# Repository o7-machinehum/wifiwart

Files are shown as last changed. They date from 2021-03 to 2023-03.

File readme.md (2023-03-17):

# Wifiwart
## Custom Non Form Factor Board
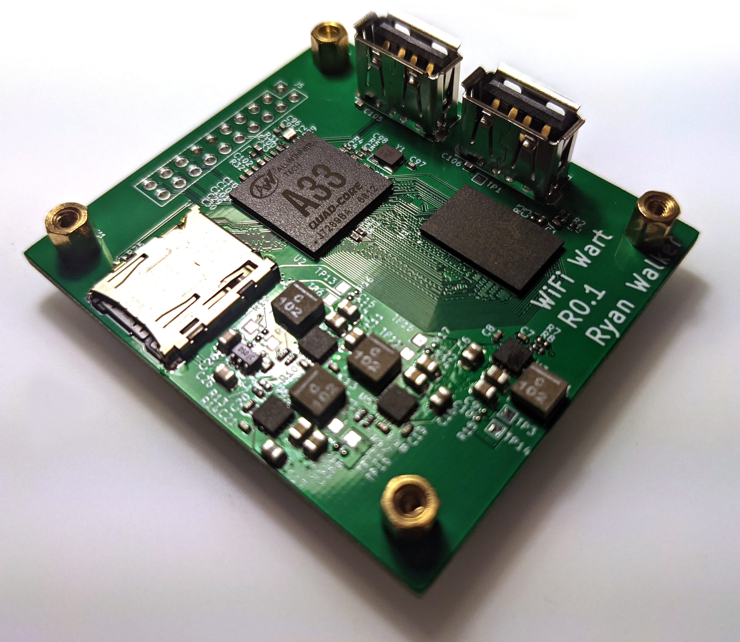
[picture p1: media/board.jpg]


## Final boards
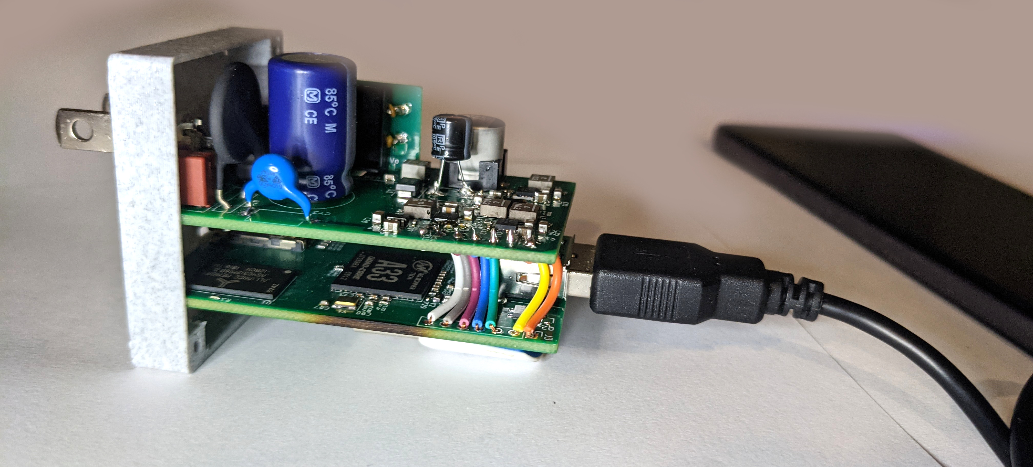
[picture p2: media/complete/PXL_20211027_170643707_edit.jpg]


The WiFiWart is an open source WiFi penetration device masquerading as a 
wall charger. It features a 1.2Ghz Cortex A7 MPU with two WiFi
chips. The electrical, mechanical and software elemenet are all completely
open source. Check out the blog series!

- [Final Blog Post](https://interruptlabs.ca/2021/10/25/I-put-a-WiFi-router-into-a-phone-charger-Final-Post/)
- [Blog Post #3](https://interruptlabs.ca/2021/09/22/I'm-not-putting-a-WiFi-router-into-a-phone-charger-Part-3/)
- [Blog Post #2](https://interruptlabs.ca/2021/07/19/I'm-putting-a-WiFi-router-into-a-wall-charger-Part-2/)
- [Blog Post #1](https://interruptlabs.ca/2021/06/15/I'm-putting-a-WiFi-router-into-a-wall-charger-Part-1/)
- [Blog Post #0](https://interruptlabs.ca/2021/04/28/I'm-putting-a-WiFi-router-into-a-wall-charger-Part-0/)
- [Join us on Discord!](https://discord.gg/EtZT7mjNuM)

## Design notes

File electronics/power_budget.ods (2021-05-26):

DC
Vin (Vdc) | Vout (Vdc) | Iin (A) | Iout (A) | Pin (W) | Pout (W) | Supply Efficiency | Waste Heat (W)
5 | 3.3 | 0.776470588235294 | 1 | 3.88235294117647 | 3.3 | 0.85 | 0.58235294117647
5 | 3 | 0.705882352941176 | 1 | 3.52941176470588 | 3 | 0.85 | 0.529411764705883
3.3 | 2.5 | 0.3 | 0.3 | 0.99 | 0.75 | 0.757575757575758 | 0.24
5 | 1.35 | 0.635294117647059 | 2 | 3.17647058823529 | 2.7 | 0.85 | 0.476470588235294
5 | 1.1 | 1.03529411764706 | 4 | 5.17647058823529 | 4.4 | 0.85 | 0.776470588235294
 | Total: | 3.45294117647059 |  |  |  |  | 2.60470588235294
Vin (RMS) | Vin (pk) | Vout (pk) | Windings Ratio
120 | 169.705627484771 | 5.5 | 30.8555686335948

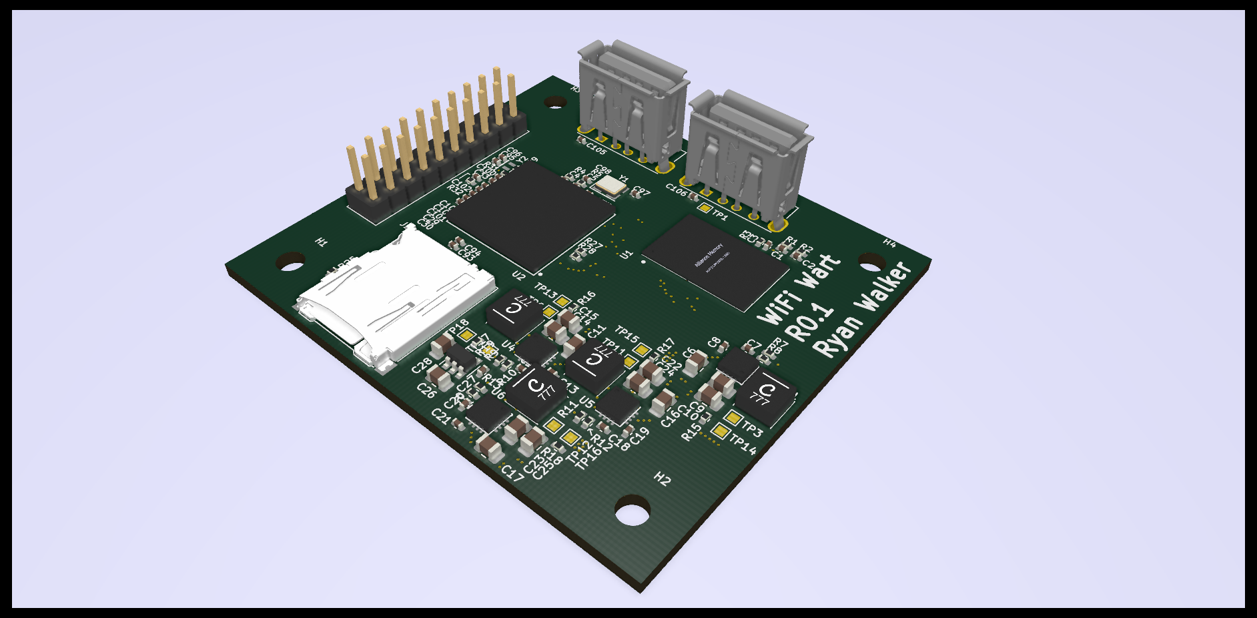
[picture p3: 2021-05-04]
electronics/nff_pcb/Renders/hardware3.png

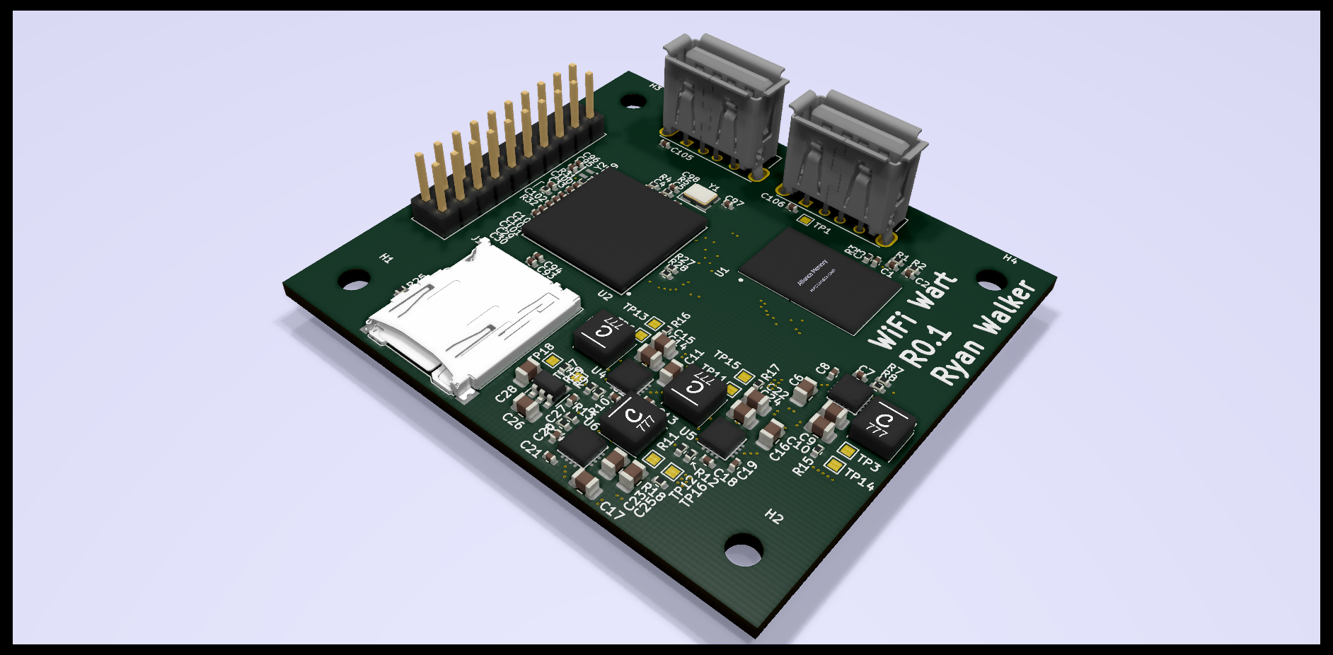
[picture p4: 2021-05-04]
electronics/nff_pcb/Renders/hardware2.png

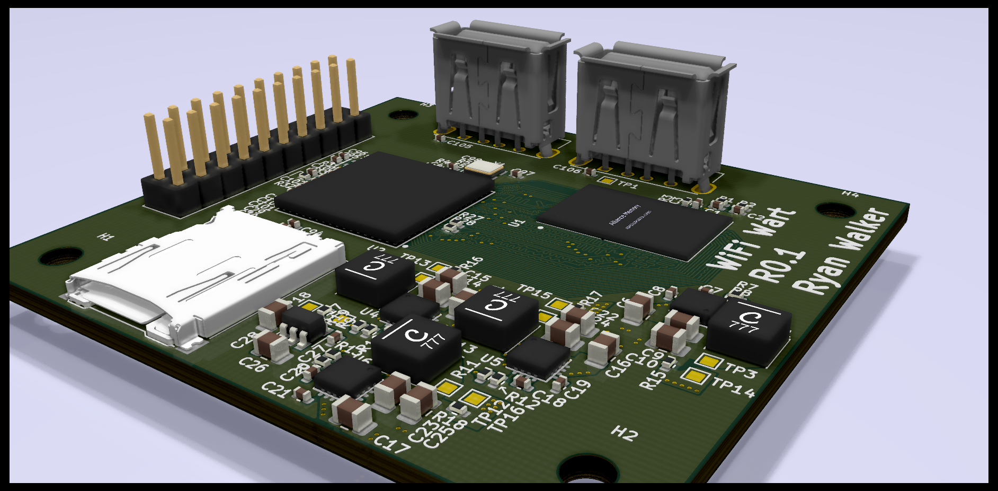
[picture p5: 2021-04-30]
electronics/nff_pcb/Renders/hardware4.png

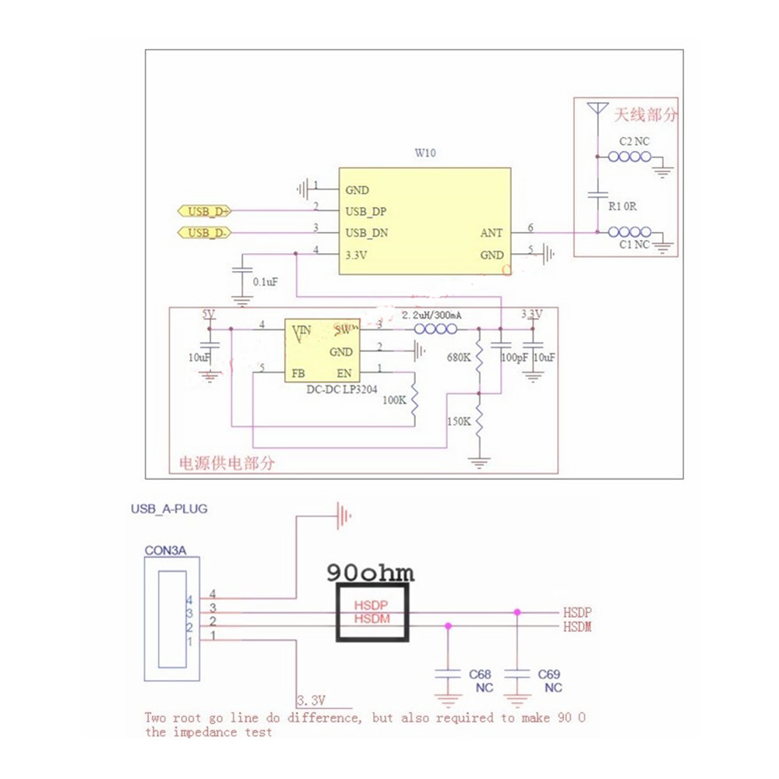
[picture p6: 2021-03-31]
electronics/datasheets/wifi_sch.jpg

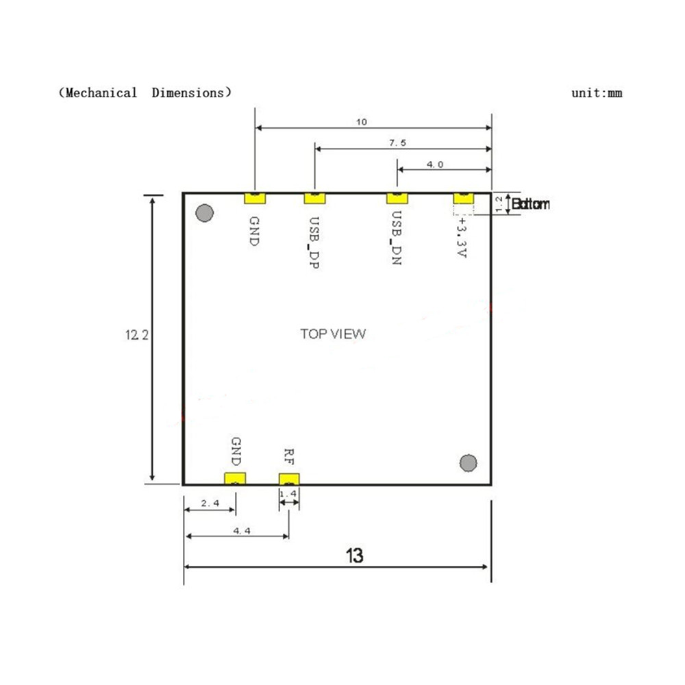
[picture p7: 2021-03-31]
electronics/datasheets/wifi_layout.jpg

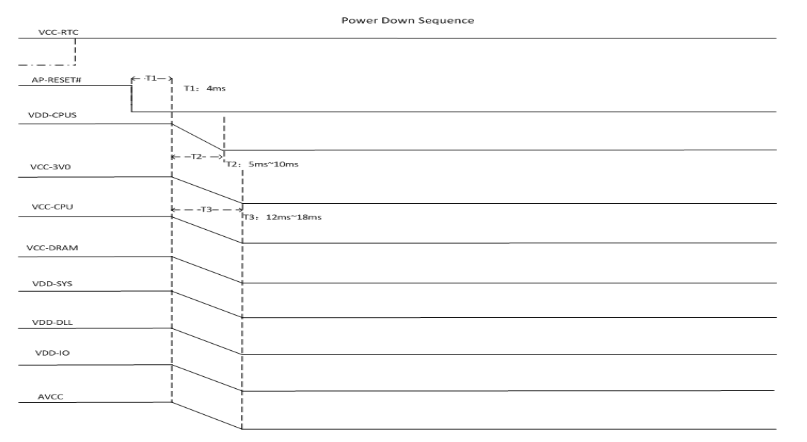
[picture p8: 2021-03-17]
electronics/datasheets/pd.png

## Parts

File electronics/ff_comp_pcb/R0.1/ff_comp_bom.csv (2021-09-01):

Ref | Qnty | Value | Footprint | Part Number
AE1, AE2, | 2 | Antenna_Dipole | Connector_Coaxial:U.FL_Hirose_U.FL-R-SMT-1_Vertical | U.FL-R-SMT-1(10)
C1, C2, C3, C4, C5, C6, C8, C10, C11, C30, C31, C32, C33, C37, C38, C40, C42, C43, C48, C59, C64, C65, C66, C67, C68, C73, C74, C75, C76, C77, C78, C79, C80, C82, C85, C86, C87, C89, C90, C91, C92, C93, C100, C104, | 44 | 100nF | Capacitor_SMD:C_0402_1005Metric | CC0402KRX7R7BB104
C7, C9, C53, C54, C55, C56, C69, C70, C94, | 9 | 22uF | Capacitor_SMD:C_0402_1005Metric | GRM155R60J226ME11D
C29, C99, C102, C103, | 4 | 10uF | Capacitor_SMD:C_0402_1005Metric | CL05A106MQ5NUNC
C95, C96, | 2 | 10pF | Capacitor_SMD:C_0402_1005Metric | CC0402JRNPO9BN100
C97, C98, | 2 | 30pF | Capacitor_SMD:C_0402_1005Metric | CC0402JRNPO9BN300
C101, | 1 | 1uF | Capacitor_SMD:C_0402_1005Metric | CL05A105KO5NNNC
J1, | 1 | Micro_SD_Card_Det_Hirose_DM3AT | Connector_Card:microSD_HC_Hirose_DM3AT-SF-PEJM5 | DM3AT-SF-PEJM5
J2, | 1 | USB_A | Connector_USB:USB_A_Molex_67643_Horizontal | 676430910
J3, | 1 | Conn_01x07_Female | Connector_PinHeader_2.54mm:PinHeader_1x07_P2.54mm_Vertical
J4, | 1 | Conn_01x03_Male | Connector_PinHeader_2.54mm:PinHeader_1x03_P2.54mm_Vertical
Q1, | 1 | Q_PMOS_GSD | Package_TO_SOT_SMD:SOT-23 | SSM3J328R,LF
Q2, | 1 | Q_NPN_BEC | Package_TO_SOT_SMD:SOT-23 | MMBT2369ALT1G
R1, R2, R4, R5, | 4 | 1k | Resistor_SMD:R_0402_1005Metric | 4-1879208-9
R3, R6, | 2 | 240R | Resistor_SMD:R_0402_1005Metric | 0402WGF2400TCE
R7, R20, R21, R23, R24, R25, | 6 | 100k | Resistor_SMD:R_0402_1005Metric | CR0402-JW-104GLF
R22, R30, | 2 | 10k | Resistor_SMD:R_0402_1005Metric | RC0402JR-0710KL
R26, | 1 | 0R | Resistor_SMD:R_0402_1005Metric | RC0402JR-070RL
R27, R28, | 2 | 22R | Resistor_SMD:R_0402_1005Metric | RC0402JR-0722RL
R29, R31, | 2 | 10M | Resistor_SMD:R_0402_1005Metric | 0402WGJ0106TCE
R32, | 1 | 200k | Resistor_SMD:R_0402_1005Metric | RC0402FR-07200KL
TP1, | 1 | TestPoint | TestPoint:TestPoint_Pad_2.0x2.0mm
U1, | 1 | AS4C512M16D3L-12BIN | AS4C512M16D3L:Alliance_Memory-AS4C512M16D3L-12BIN-0-0-IPC_A | AS4C512M16D3L-12BIN
U2, | 1 | A33 | A33_FP:Allwinner_Technology_Co.,_Ltd.-A33-0 | A33
U3, | 1 | FSUSB42MUX | Package_SO:MSOP-10_3x3mm_P0.5mm | FSUSB42MUX
U4, U5, | 2 | RTL8188CUS | realtek:RTL8188CUS | RTL8188CUS
Y1, | 1 | 24Mhz | Crystal:Crystal_SMD_Abracon_ABM8G-4Pin_3.2x2.5mm | ABM8G-24.000MHZ-18-D2Y-T
Y2, | 1 | 32.768khz | Abracon:Abracon-ABS05-0-0-MFG | ABS05-32.768KHZ-9-T

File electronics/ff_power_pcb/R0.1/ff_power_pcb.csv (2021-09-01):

Ref | Qnty | Value | Footprint | Part Number
C1, | 1 | 0.1uF | Capacitor_SMD:C_1206_3216Metric | C3216X7T2V104M160AA
C2, | 1 | 10uF | Capacitor_THT:C_Radial_D12.5mm_H20.0mm_P5.00mm | UVR2W100MHD
C4, | 1 | 470uF | Capacitor_SMD:CP_Elec_10x12.5 | GYA1C471MCW1GS
C5, | 1 | 100uF | Capacitor_SMD:CP_Elec_6.3x5.8 | 16ML100MEFC6.3X7
C6, C9, C10, C11, C14, C15, C16, C17, C22, C23, C24, C25, | 12 | 22uF | Capacitor_SMD:C_0805_2012Metric | CL21A226MQQNNNE
C7, C12, C18, C20, | 4 | 10nF | Capacitor_SMD:C_0402_1005Metric | CL05B103KB5NNNC
C8, C13, | 2 | 450pF | Capacitor_SMD:C_0402_1005Metric | CL05B471KB5NNNC
C19, C21, | 2 | 5nF | Capacitor_SMD:C_0402_1005Metric | CC0402KRX7R9BB562
C26, C28, | 2 | 10uF | Capacitor_SMD:C_0805_2012Metric | GRM21BR70J106KE76L
C27, | 1 | 0.1uF | Capacitor_SMD:C_0402_1005Metric | CC0402KRX7R7BB104
C29, | 1 | 0.1uF | Capacitor_SMD:C_0603_1608Metric | C1608X7R1H104K080AA
CY3, | 1 | 1.0nF | Capacitor_THT:C_Disc_D7.5mm_W5.0mm_P10.00mm | C901U102MUVDBA7317
D1, | 1 | SMBJ7.0A | Diode_SMD:D_SMB | SMBJ7.0A
F1, | 1 | 1A/300V Slow | Fuse:Fuse_Littelfuse_395Series | 36911000000
J1, J2, | 2 | Conn_01x01_Female | mains_blade:IRL_00
J3, | 1 | Conn_01x07_Male | Connector_PinSocket_2.54mm:PinSocket_1x07_P2.54mm_Vertical
L1, L2, L3, L4, | 4 | 1uH | Inductor_SMD:L_Coilcraft_XxL4020 | XAL4020-102ME
L5, | 1 | 1.2mH | Bourns:RLB9012 | RLB9012-122KL
L6, | 1 | 4.7uH | Inductor_SMD:L_Coilcraft_XxL4030 | XAL4030-472ME
NTC1, | 1 | 10R | Capacitor_THT:C_Disc_D9.0mm_W2.5mm_P5.00mm | B57234S0100M051
PS1, | 1 | PBO-5C-5 | CUI:CONV_PBO-5C-12 | PBO-5C-5
R7, | 1 | 470k | Resistor_SMD:R_0402_1005Metric | RTT024703FTH
R8, | 1 | 150k | Resistor_SMD:R_0402_1005Metric | RC0402FR-07150KL
R9, | 1 | 330k | Resistor_SMD:R_0402_1005Metric | RC0402FR-07330KL
R10, | 1 | 120k | Resistor_SMD:R_0402_1005Metric | RTT021203FTH
R11, | 1 | 110k | Resistor_SMD:R_0402_1005Metric | RTT021103FTH
R12, | 1 | 160k | Resistor_SMD:R_0402_1005Metric | 0402WGF1603TCE
R13, | 1 | 82k | Resistor_SMD:R_0402_1005Metric | 0402WGF8202TCE
R14, | 1 | 220k | Resistor_SMD:R_0402_1005Metric | ERJPA2F2203X
R15, R16, R17, R18, R19, | 5 | 0R | Resistor_SMD:R_0402_1005Metric | RC0402JR-070RL
U3, U4, U5, U6, | 4 | TPS62095RGTR | TI:TI_RTE_S-PWQFN-N16 | TPS62095RGTR
U7, | 1 | AP131-25 | Package_TO_SOT_SMD:SOT-23-5 | AP131-25

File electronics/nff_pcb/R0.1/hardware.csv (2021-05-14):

Source: | /home/machinehum/projects/wifiwart/electronics/pcb/hardware.sch
Date: | Thu 13 May 2021 02:48:55 PM PDT
Tool: | Eeschema 5.1.10
Generator: | projects/wifiwart/electronics/pcb/generate_bom.py
Component Count: | 145
Ref | Qnty | Value | Footprint | Part Number
C1, C2, C3, C4, C5, C30, C31, C32, C33, C37, C38, C40, C42, C43, C48, C59, C64, C65, C66, C67, C68, C73, C74, C75, C76, C77, C78, C79, C80, C82, C85, C86, C87, C89, C90, C91, C92, C93, C100, C104, | 40 | 100nF | Capacitor_SMD:C_0402_1005Metric | CC0402KRX7R7BB104
C6, C9, C10, C11, C14, C15, C16, C17, C22, C23, C24, C25, | 12 | 22uF | Capacitor_SMD:C_0805_2012Metric | CL21A226MQQNNNE
C7, C12, C18, C20, | 4 | 10nF | Capacitor_SMD:C_0402_1005Metric | CL05B103KB5NNNC
C8, C13, | 2 | 450pF | Capacitor_SMD:C_0402_1005Metric | CL05B471KB5NNNC
C19, C21, | 2 | 5nF | Capacitor_SMD:C_0402_1005Metric | CC0402KRX7R9BB562
C26, C28, | 2 | 10uF | Capacitor_SMD:C_0805_2012Metric | GRM21BR70J106KE76L
C27, | 1 | 0.1uF | Capacitor_SMD:C_0402_1005Metric | CC0402KRX7R7BB104
C29, C99, C102, C103, C105, C106, | 6 | 10uF | Capacitor_SMD:C_0402_1005Metric | CL05A106MQ5NUNC
C53, C54, C55, C56, C69, C70, C94, | 7 | 22uF | Capacitor_SMD:C_0402_1005Metric | GRM155R60J226ME11D
C95, C96, | 2 | 10pF | Capacitor_SMD:C_0402_1005Metric | CC0402JRNPO9BN100
C97, C98, | 2 | 30pF | Capacitor_SMD:C_0402_1005Metric | CC0402JRNPO9BN300
C101, | 1 | 1uF | Capacitor_SMD:C_0402_1005Metric | CL05A105KO5NNNC
H1, H2, H3, H4, | 4 | MountingHole | MountingHole:MountingHole_3.2mm_M3
J1, | 1 | Micro_SD_Card_Det_Hirose_DM3AT | Connector_Card:microSD_HC_Hirose_DM3AT-SF-PEJM5 | DM3AT-SF-PEJM5
J2, J3, | 2 | USB_A | Connector_USB:USB_A_Molex_105057_Vertical | 1050570001
J5, | 1 | Conn_02x10_Odd_Even | Connector_PinHeader_2.54mm:PinHeader_2x10_P2.54mm_Vertical
L1, L2, L3, L4, | 4 | 1uH | Inductor_SMD:L_Coilcraft_XxL4020 | XAL4020-102ME
R1, R2, R4, R5, | 4 | 1k | Resistor_SMD:R_0402_1005Metric | 4-1879208-9
R3, R6, | 2 | 240R | Resistor_SMD:R_0402_1005Metric | 0402WGF2400TCE
R7, | 1 | 470k | Resistor_SMD:R_0402_1005Metric | RTT024703FTH
R8, | 1 | 150k | Resistor_SMD:R_0402_1005Metric | RC0402FR-07150KL
R9, | 1 | 330k | Resistor_SMD:R_0402_1005Metric | RC0402FR-07330KL
R10, | 1 | 120k | Resistor_SMD:R_0402_1005Metric | RTT021203FTH
R11, | 1 | 110k | Resistor_SMD:R_0402_1005Metric | RTT021103FTH
R12, | 1 | 160k | Resistor_SMD:R_0402_1005Metric | 0402WGF1603TCE
R13, | 1 | 82k | Resistor_SMD:R_0402_1005Metric | 0402WGF8202TCE
R14, | 1 | 220k | Resistor_SMD:R_0402_1005Metric | ERJPA2F2203X
R15, R16, R17, R18, R19, R26, | 6 | 0R | Resistor_SMD:R_0402_1005Metric | RC0402JR-070RL
R20, R21, R23, R24, R25, | 5 | 100k | Resistor_SMD:R_0402_1005Metric | CR0402-JW-104GLF
R22, R30, | 2 | 10k | Resistor_SMD:R_0402_1005Metric | RC0402JR-0710KL
R27, R28, | 2 | 22R | Resistor_SMD:R_0402_1005Metric | RC0402JR-0722RL
R29, R31, | 2 | 10M | Resistor_SMD:R_0402_1005Metric | 0402WGJ0106TCE
R32, | 1 | 200k | Resistor_SMD:R_0402_1005Metric | RC0402FR-07200KL
TP1, TP3, TP6, TP11, TP12, TP13, TP14, TP15, TP16, TP17, TP18, | 11 | TestPoint | TestPoint:TestPoint_Pad_1.0x1.0mm | ~
U1, | 1 | AS4C512M16D3L-12BIN | AS4C512M16D3L:Alliance_Memory-AS4C512M16D3L-12BIN-0-0-IPC_A | AS4C512M16D3L-12BIN
U2, | 1 | A33 | A33_FP:Allwinner_Technology_Co.,_Ltd.-A33-0 | A33
U3, U4, U5, U6, | 4 | TPS62095RGTR | TI:TI_RTE_S-PWQFN-N16 | TPS62095RGTR
U7, | 1 | AP131-25 | Package_TO_SOT_SMD:SOT-23-5 | AP131-25
Y1, | 1 | 24Mhz | Crystal:Crystal_SMD_Abracon_ABM8G-4Pin_3.2x2.5mm | ABM8G-24.000MHZ-18-D2Y-T
Y2, | 1 | 32.768khz | Abracon:Abracon-ABS05-0-0-MFG | ABS05-32.768KHZ-9-T

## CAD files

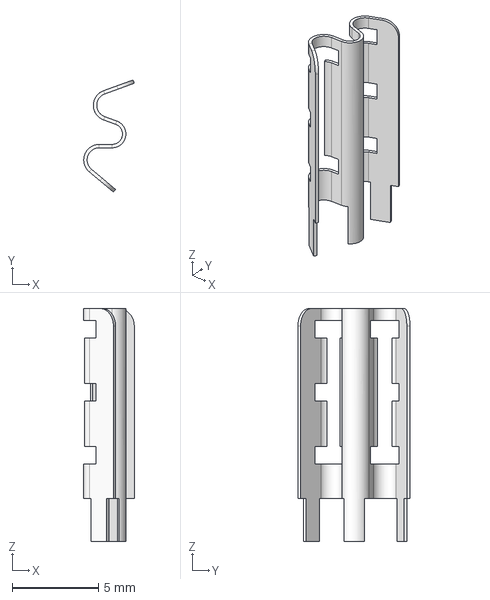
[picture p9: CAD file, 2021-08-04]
electronics/ff_power_pcb/step/mains_blade.step
2.93 x 6.49 x 13.5 mm

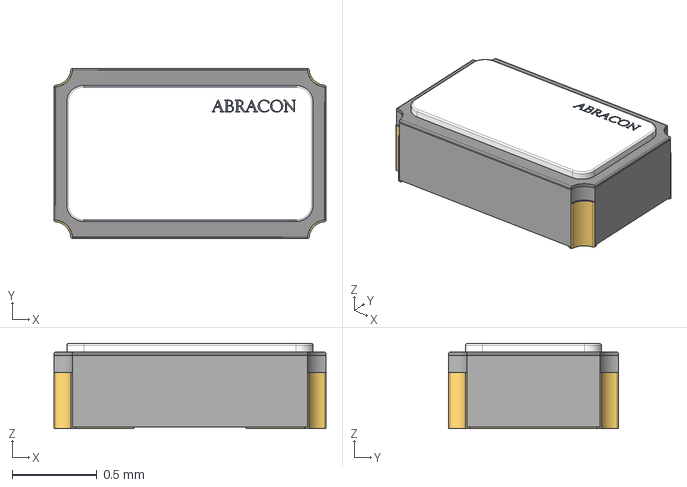
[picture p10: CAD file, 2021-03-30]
electronics/ff_comp_pcb/Abracon/eec.models/Abracon_-_ABS05-32.768KHZ-9-T.step
1.60 x 1.00 x 0.501 mm

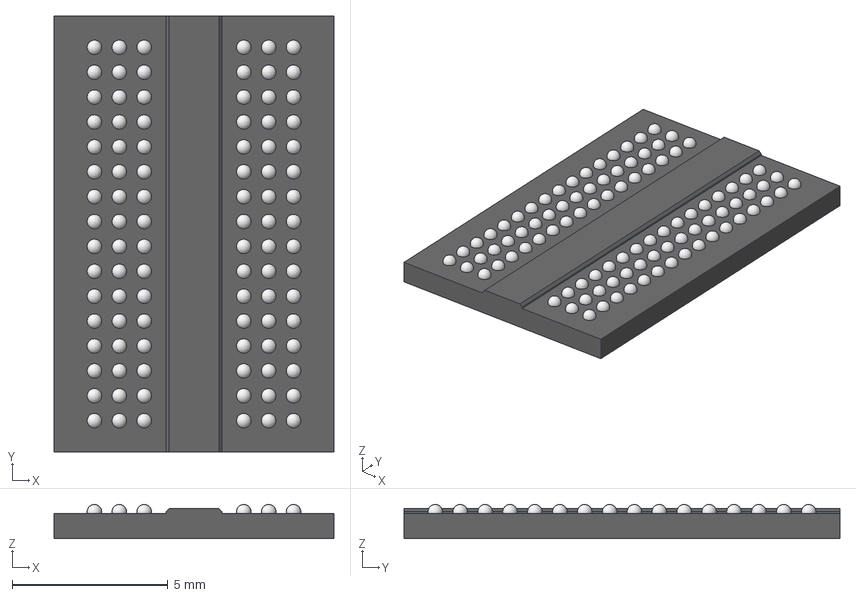
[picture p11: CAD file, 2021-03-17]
electronics/ff_comp_pcb/AS4C512M16D3L/eec.models/Alliance_Memory_-_AS4C512M16D3L-12BIN.step
9.00 x 14.0 x 1.09 mm
Part1cvcvcv
Part2sdsdsdsd x 48
Part2sdsdsdsd_MIR x 48

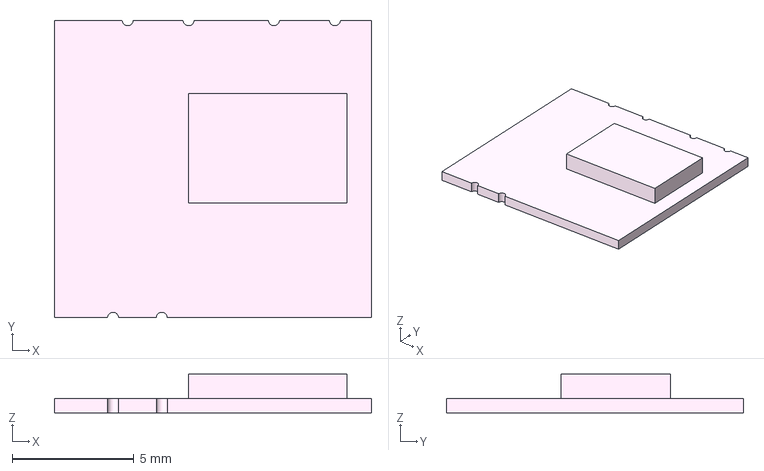
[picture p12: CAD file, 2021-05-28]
electronics/ff_comp_pcb/realtek/RTL8188CUS_module-Body.step
13.0 x 12.2 x 1.58 mm

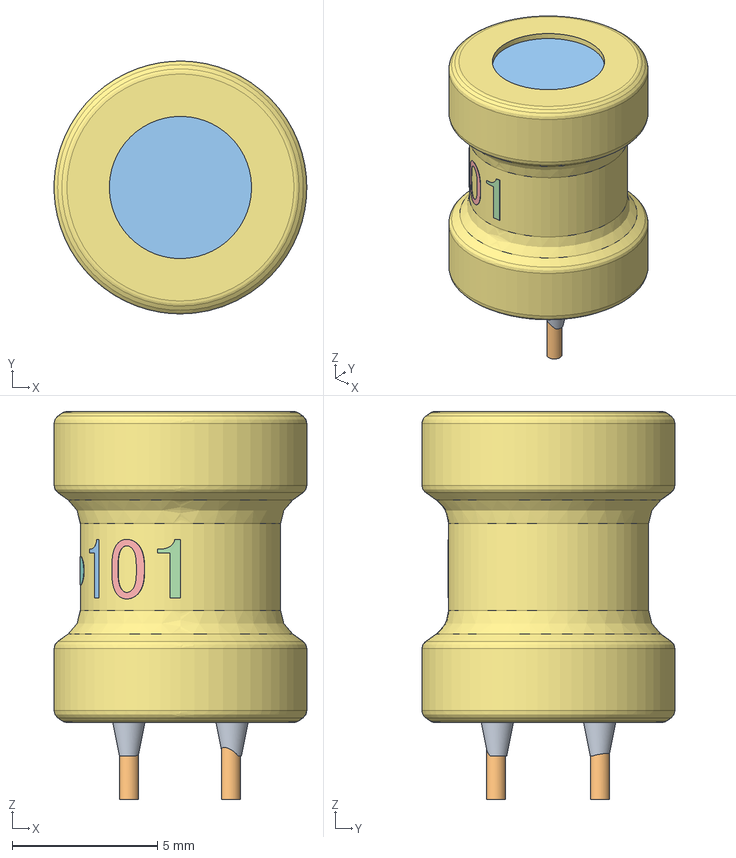
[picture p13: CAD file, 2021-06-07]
electronics/ff_power_pcb/Bourns/rlb9012_short.stp
8.70 x 8.70 x 13.3 mm
Slice.0
Slice.2
Slice.3
Slice.4
Slice.5
Slice.6
Slice.8
Slice.9
Slice.10
Slice.11
Slice.12
Slice.13
Slice.14
Slice.15
Slice.16
Slice.17
Slice.19
Slice.20
Slice.22
Slice.23
Slice.24
Slice.25
Slice.26
Slice.27
Slice.28
Slice.29
Slice.30
Slice.31
Slice.32
Slice.33
Slice.34
Slice.35
Slice.36
Slice.37
Slice.38
Slice.39
Slice.40
Slice.41
Slice.42
Slice.43
Slice.44
Slice.45
Slice.46
Slice.47
Slice.48
Slice.49
Slice.50
Slice.51
Slice.52
Slice.53
Slice.54
Slice.55
Slice.56
Slice.57
Slice.58
Slice.59
Slice.60
Slice.61
Slice.62
Slice.63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

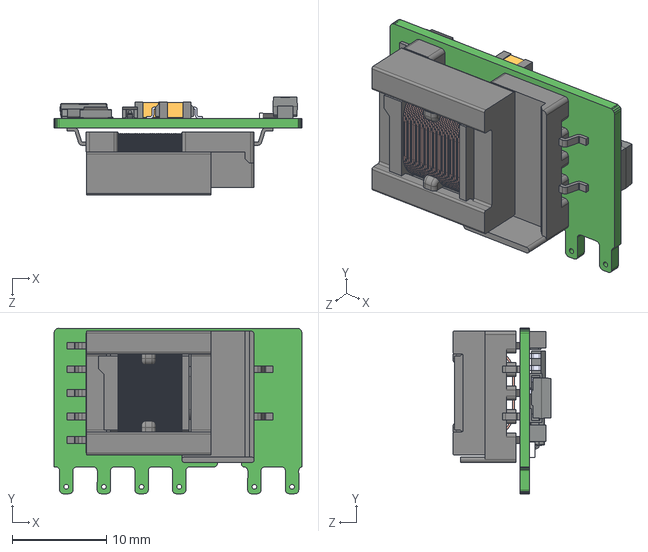
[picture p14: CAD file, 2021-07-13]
electronics/ff_power_pcb/cui/PBO-5C-12.step
26.4 x 17.6 x 10.5 mm

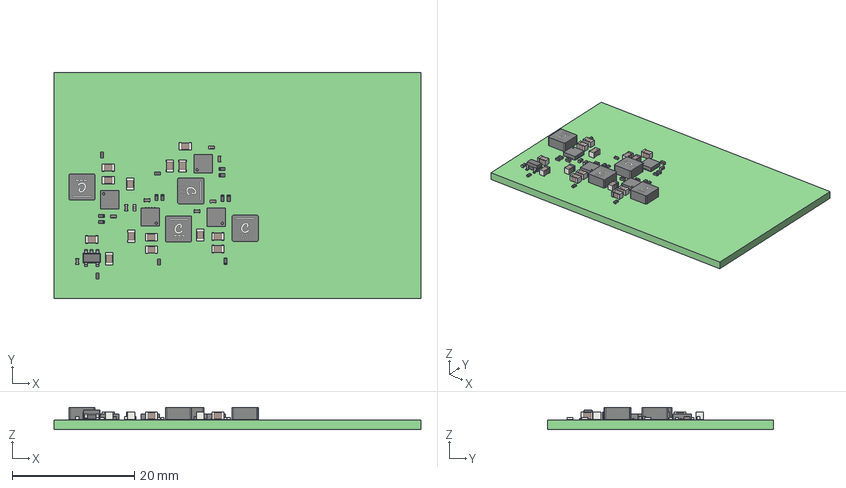
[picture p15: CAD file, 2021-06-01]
electronics/ff_power_pcb/R0.1/hardware.step
60.0 x 37.0 x 3.65 mm

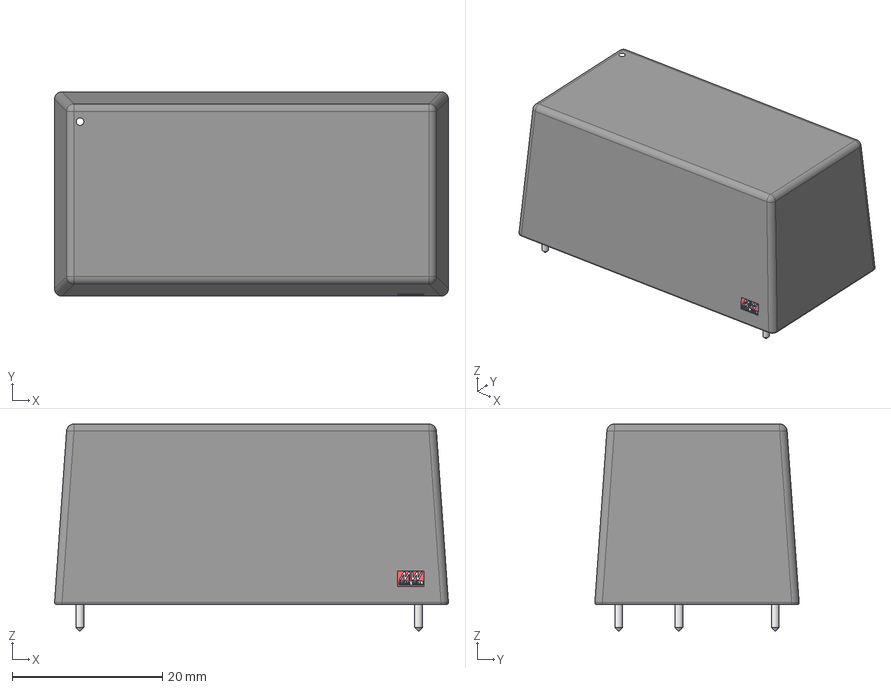
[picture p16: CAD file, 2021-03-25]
electronics/nff_pcb/MPM-15-5/eec.models/MEAN_WELL_-_MPM-15-5.step
52.4 x 27.2 x 27.5 mm
Leads
Mean Well logo
Mean Well txt
Frame
Sillkscreen dot

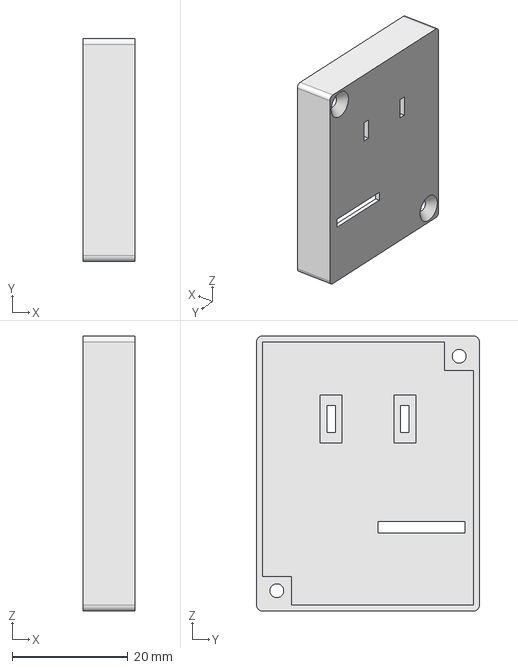
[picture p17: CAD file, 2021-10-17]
mech/lid.FCStd
9.00 x 38.5 x 47.5 mm

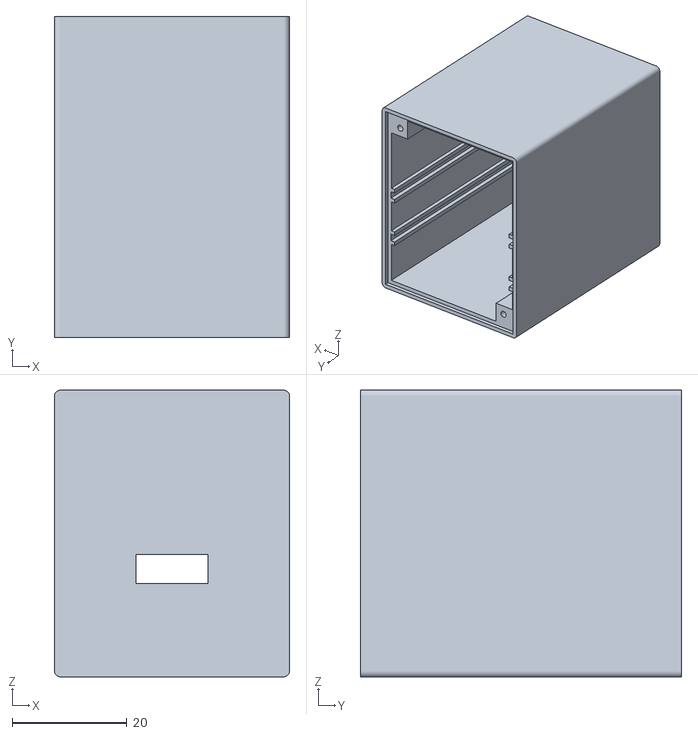
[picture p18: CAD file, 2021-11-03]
mech/out/case-ModelBody-r1.stl
41.0 x 56.0 x 50.0

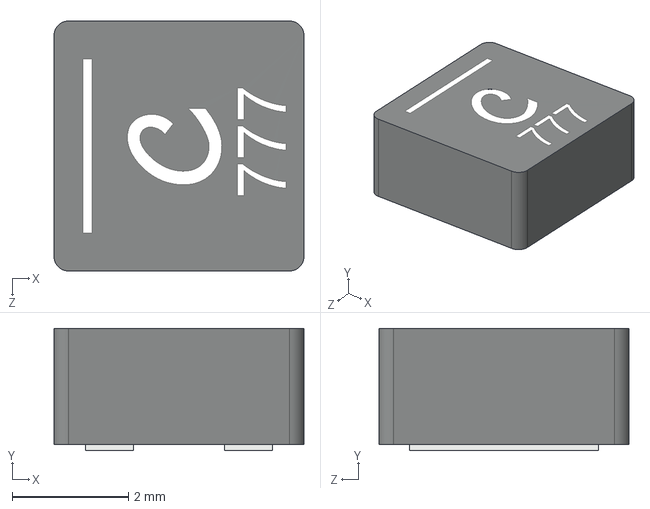
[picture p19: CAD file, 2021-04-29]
electronics/ff_comp_pcb/step/Coilcraft-XAL4020.step
4.30 x 2.10 x 4.30 mm

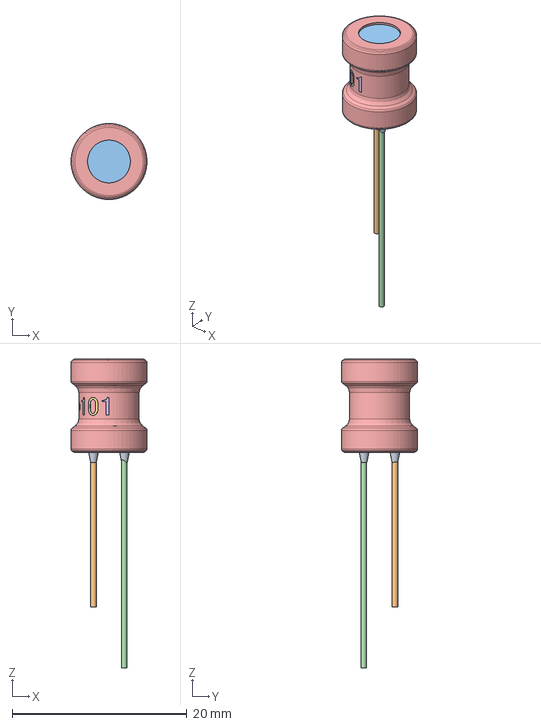
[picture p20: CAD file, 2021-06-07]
electronics/ff_power_pcb/Bourns/rlb9012.stp
8.70 x 8.70 x 35.4 mm

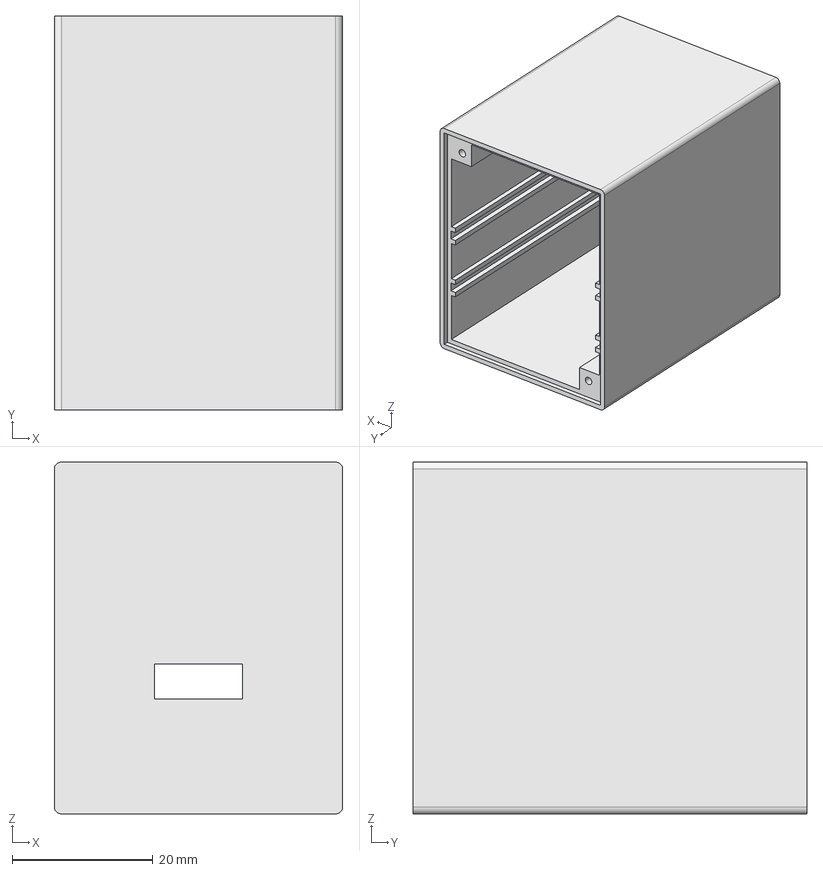
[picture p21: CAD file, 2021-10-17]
mech/case.FCStd
41.0 x 56.0 x 50.0 mm

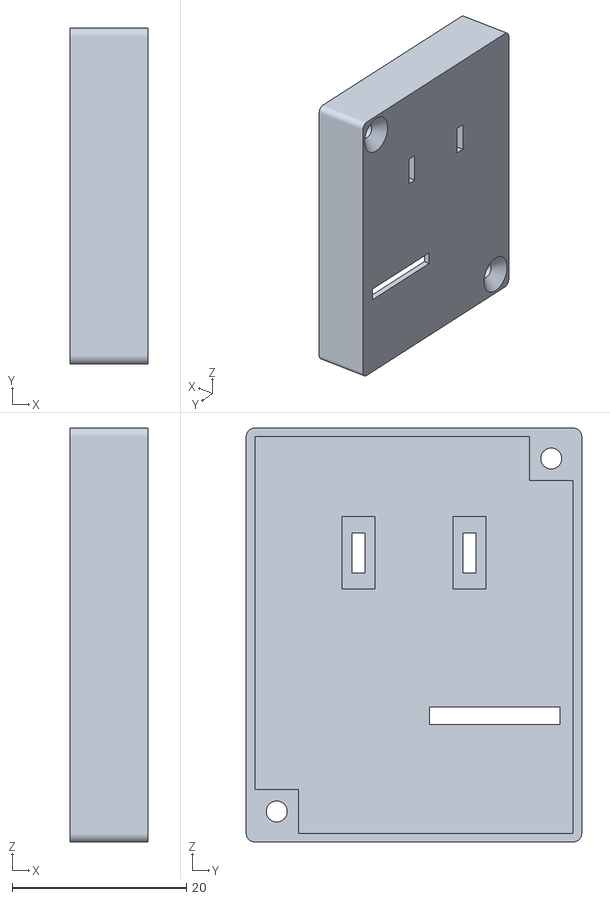
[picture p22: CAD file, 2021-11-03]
mech/out/lid-ModelBody-r1.stl
9.00 x 38.5 x 47.5

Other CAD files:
mech/out/mains_blade-Body.step
mech/mains_blade.FCStd
electronics/ff_comp_pcb/realtek/RTL8188CUS_module.FCStd
electronics/ff_comp_pcb/1050570001/1050570001.stp
electronics/ff_comp_pcb/step/676430910.stp
electronics/ff_comp_pcb/step/DM3AT-SF-PEJM5.stp
electronics/ff_comp_pcb/step/QFN-3x3.step
electronics/ff_power_pcb/Bourns/srr1208.stp
electronics/ff_power_pcb/step/36911000000.step
electronics/ff_power_pcb/step/Coilcraft-XAL4030.step
mech/36911000000.FCStd
mech/comp_pcb.FCStd
mech/out/prong-ModelParts.step
mech/patch_antenna.FCStd
mech/power_pcb.FCStd
mech/prong.FCStd

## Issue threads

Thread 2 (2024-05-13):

What's memory name

hmz06967, 2024-05-13:
Hello, I did a similar project, but I could not find the RAM model suitable for the RAM package you are using. What is the exact name of the chip you are using or can you recommend RAM models suitable for the package?

o7-machinehum, 2024-05-14:
AS4C512M16D3L-12BIN

Good luck :)

hmz06967, 2024-05-14:
But this memory is 8gb, you have installed 1gb of memory

o7-machinehum, 2024-05-14:
8GBIT = 1GBYTE :)

hmz06967, 2024-05-14:
fI'm sorry, I didn't notice it, so can you tell me whether this ram is suitable for this project? https://community.nxp.com/pwmxy87654/attachments/pwmxy87654/imx-processors/44426/2/99H02-11185D.pdf

o7-machinehum, 2024-05-14:
Looks fine to me, but of course I'm not inspecting every pin on the pdf.

Just look though both datasheets and see if the pins match up

hmz06967, 2024-05-14:
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
it just looks empty
Is it a problem ?

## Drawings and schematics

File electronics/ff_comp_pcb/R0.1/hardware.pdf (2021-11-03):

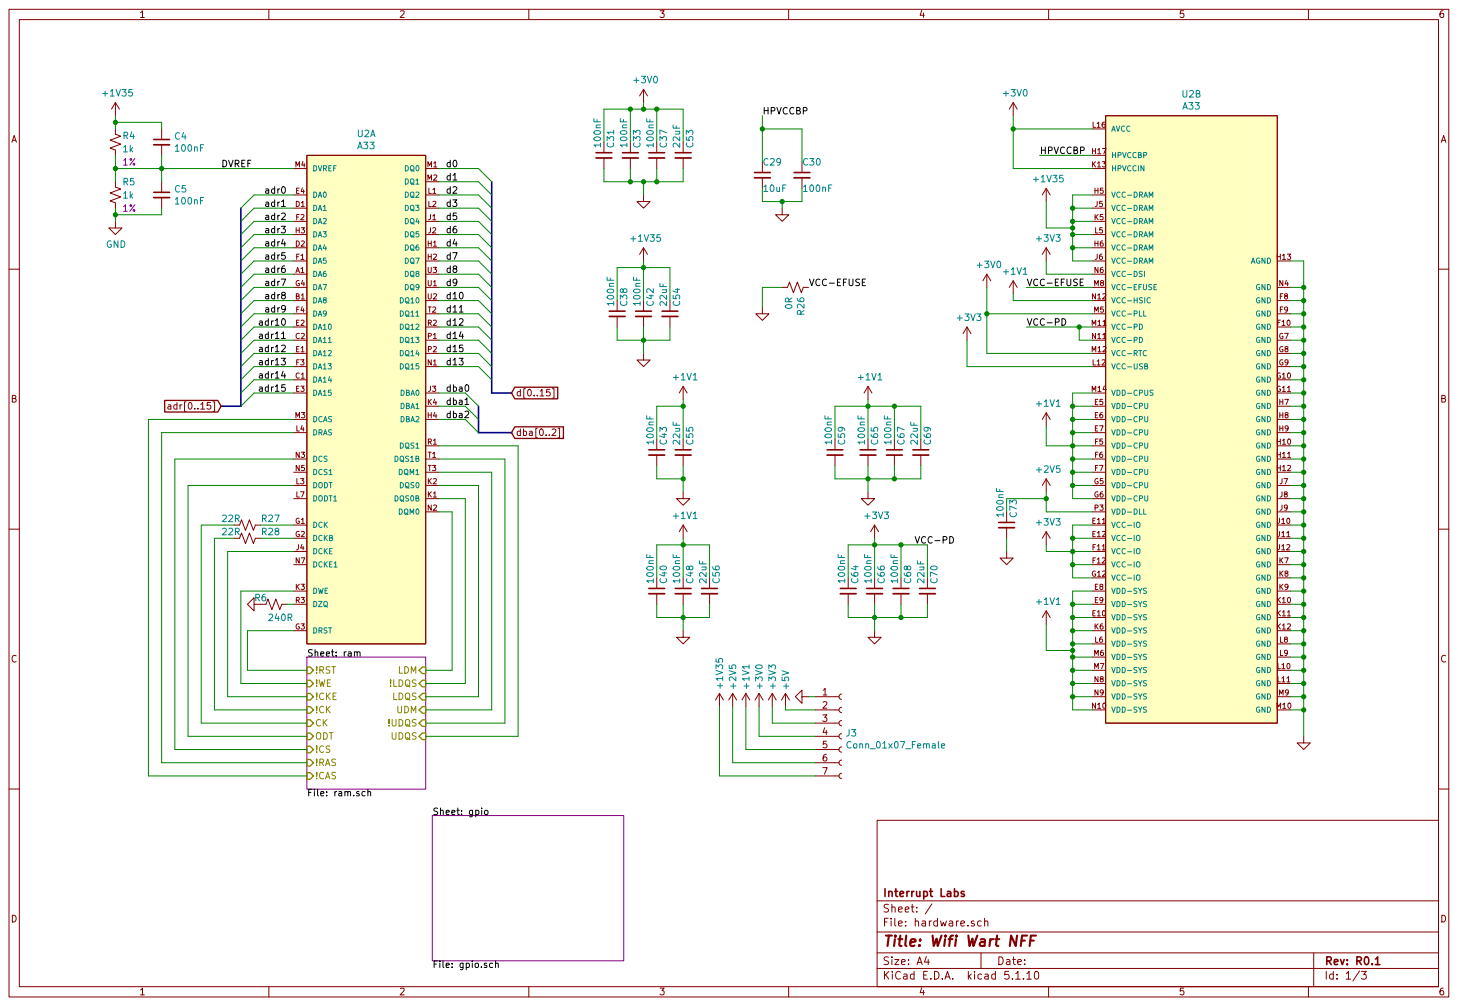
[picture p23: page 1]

Interrupt Labs
File: hardware.sch Sheet: /
Id: 1/3 Title: Wifi Wart NFF

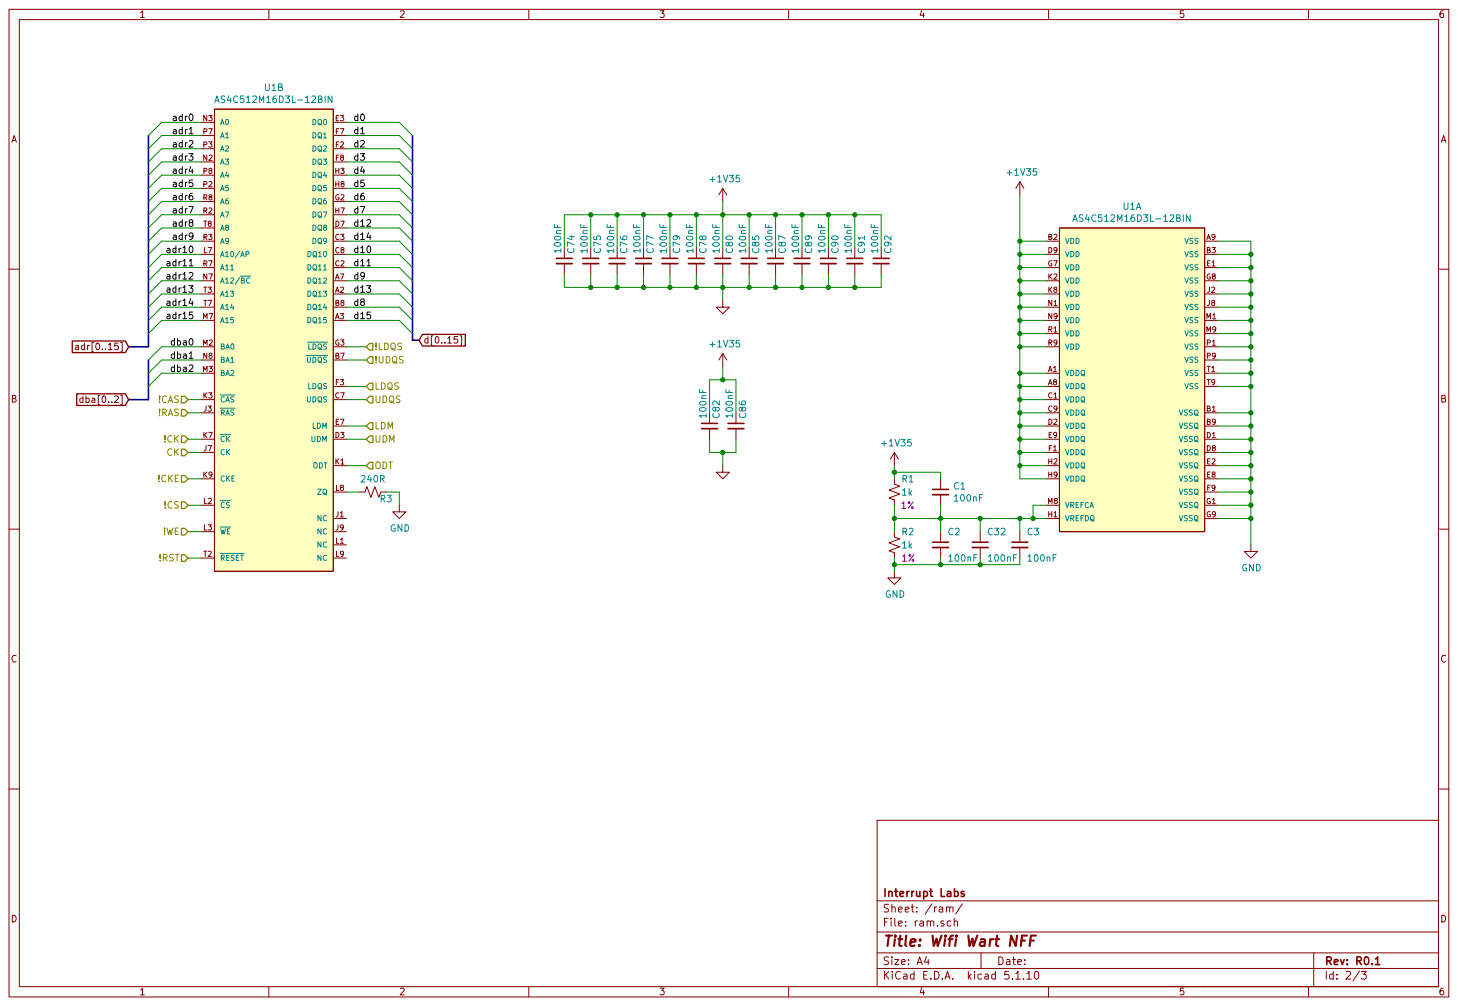
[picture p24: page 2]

File: ram.sch Sheet: /ram/
Id: 2/3 Title: Wifi Wart NFF

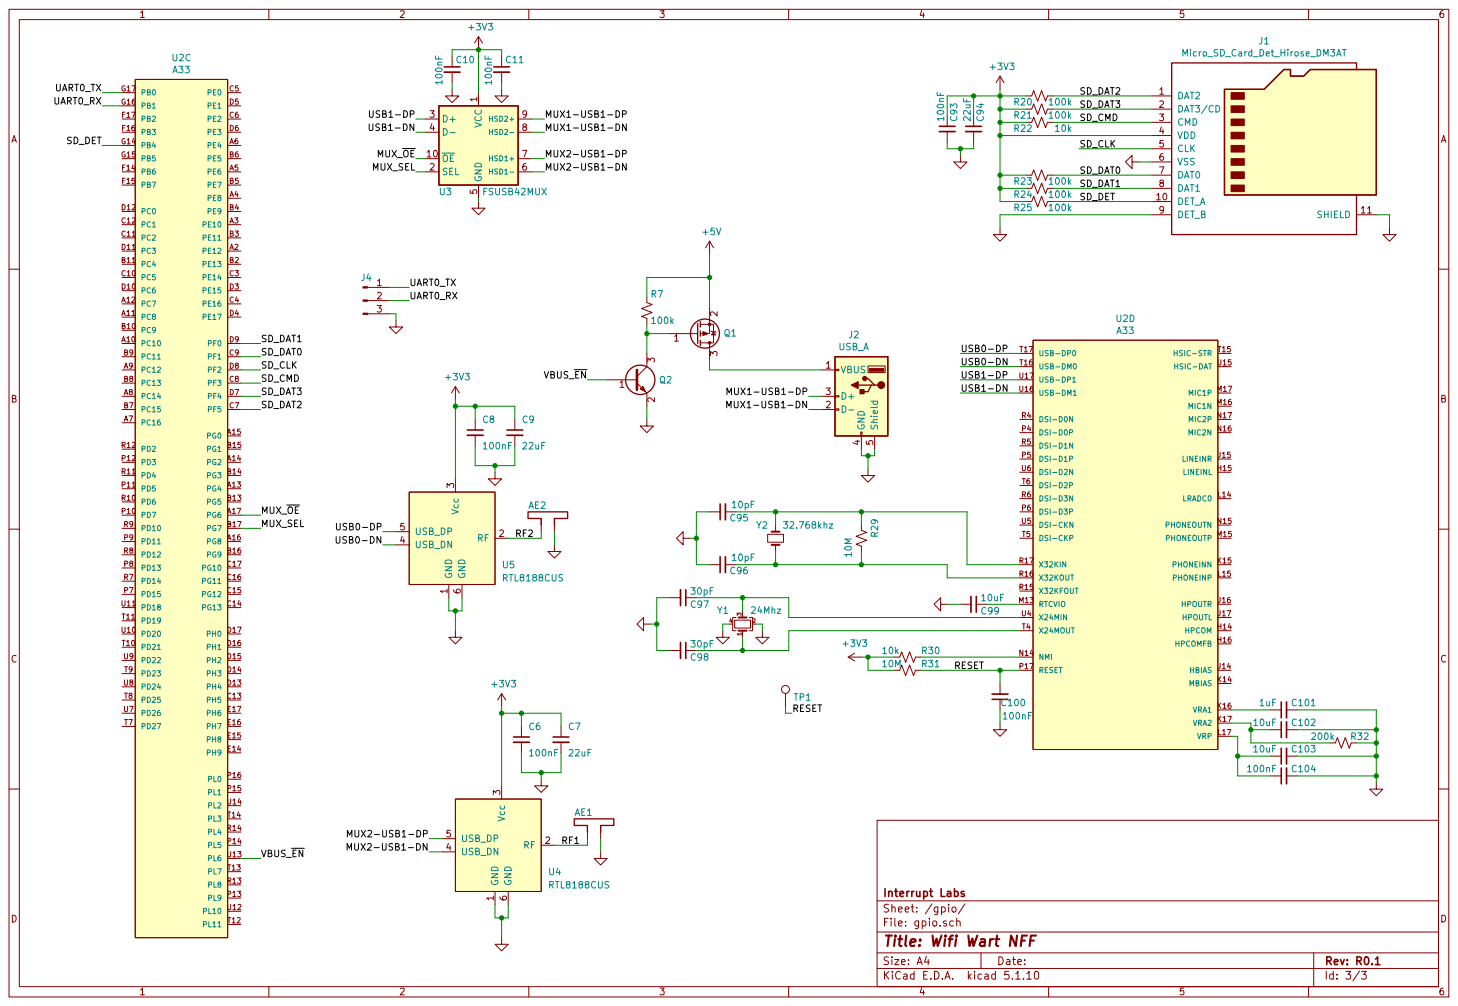
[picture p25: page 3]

Sheet: /gpio/
File: gpio.sch
Id: 3/3 Title: Wifi Wart NFF

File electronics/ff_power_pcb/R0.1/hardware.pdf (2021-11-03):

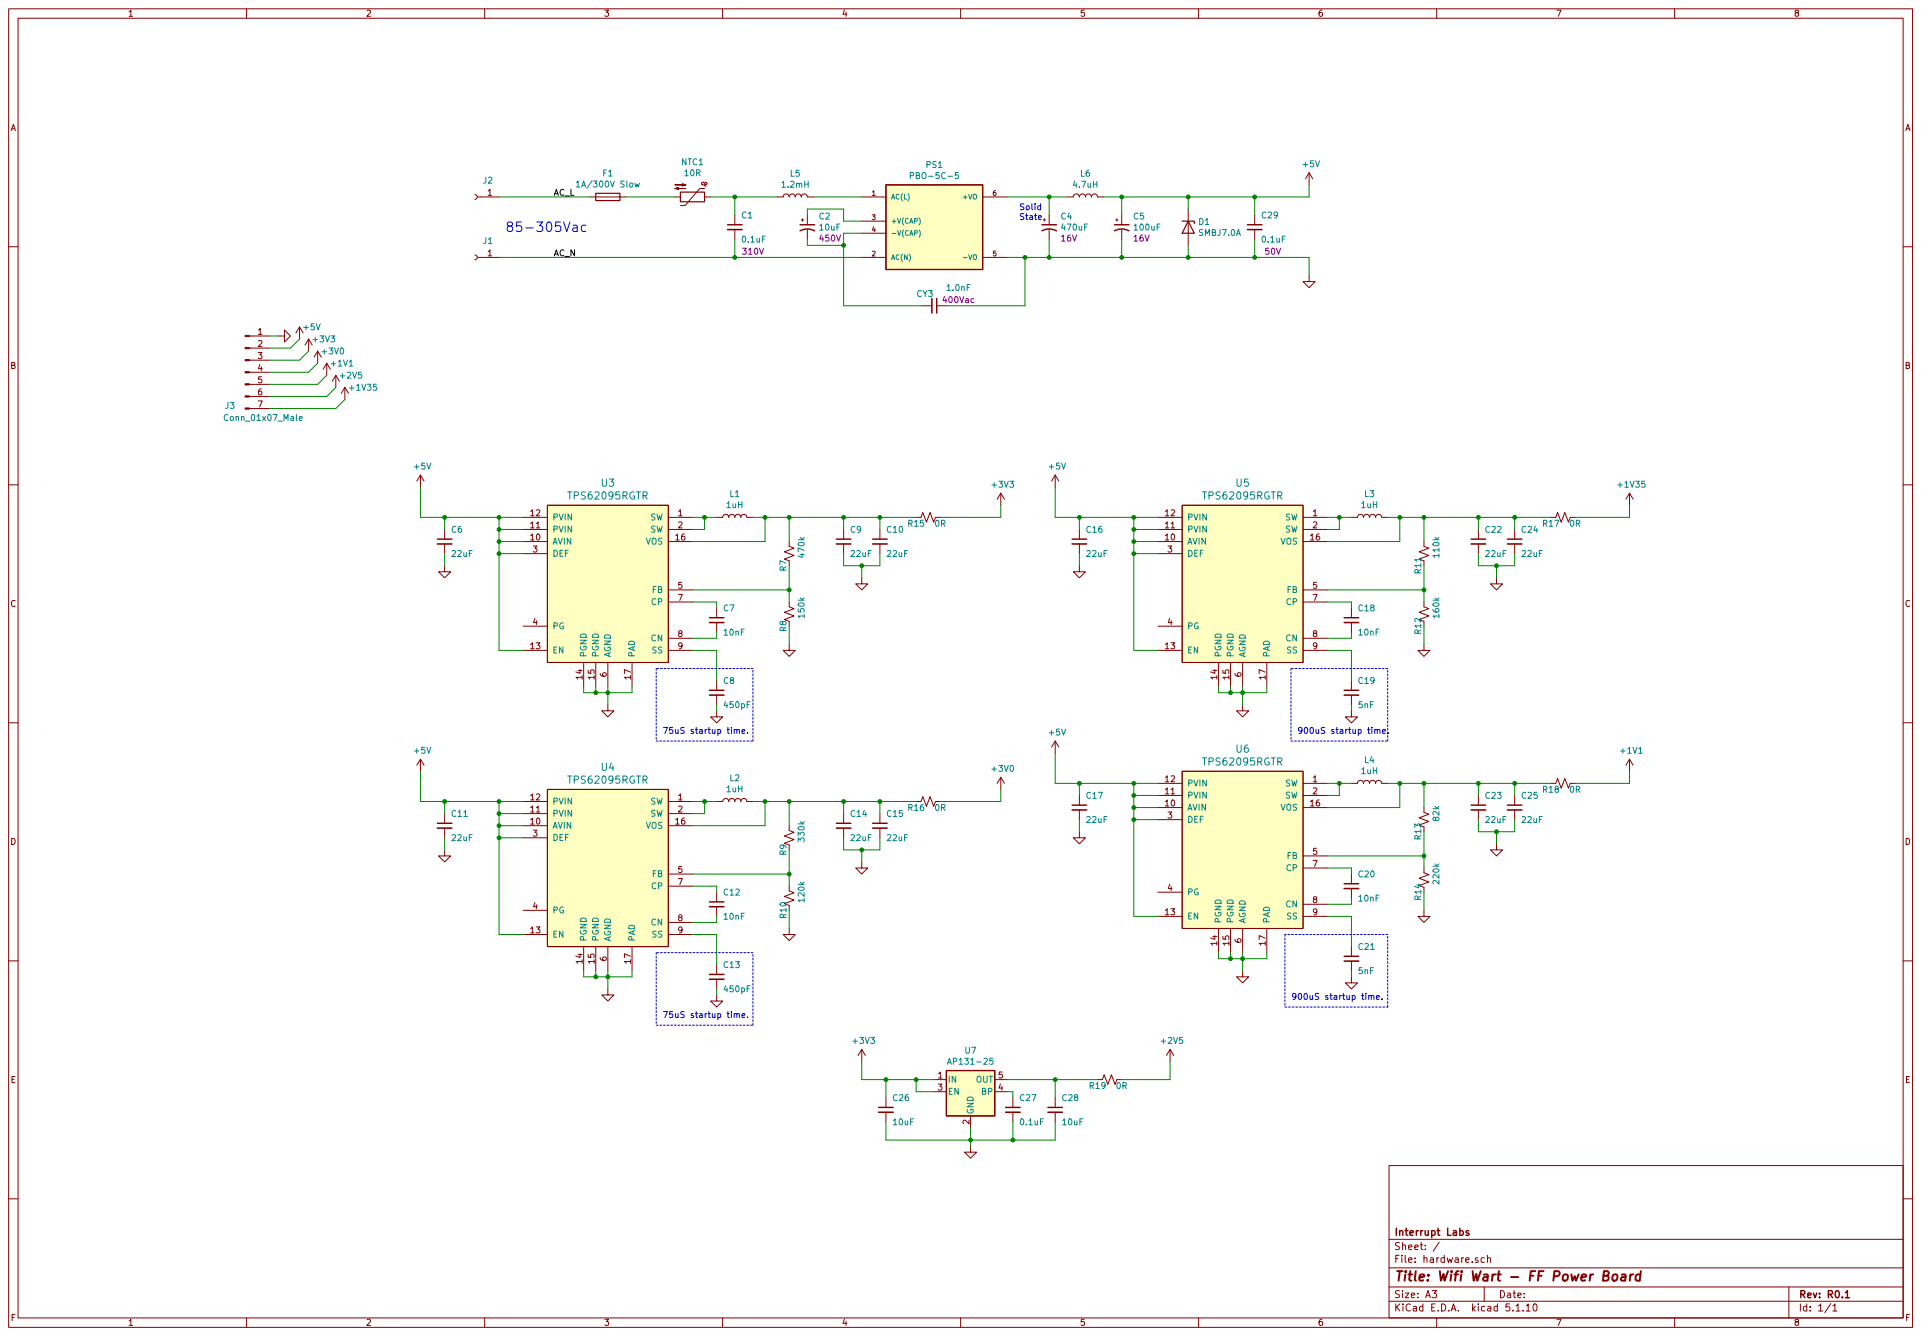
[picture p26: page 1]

Interrupt Labs
File: hardware.sch Sheet: /
Id: 1/1 Title: Wifi Wart - FF Power Board

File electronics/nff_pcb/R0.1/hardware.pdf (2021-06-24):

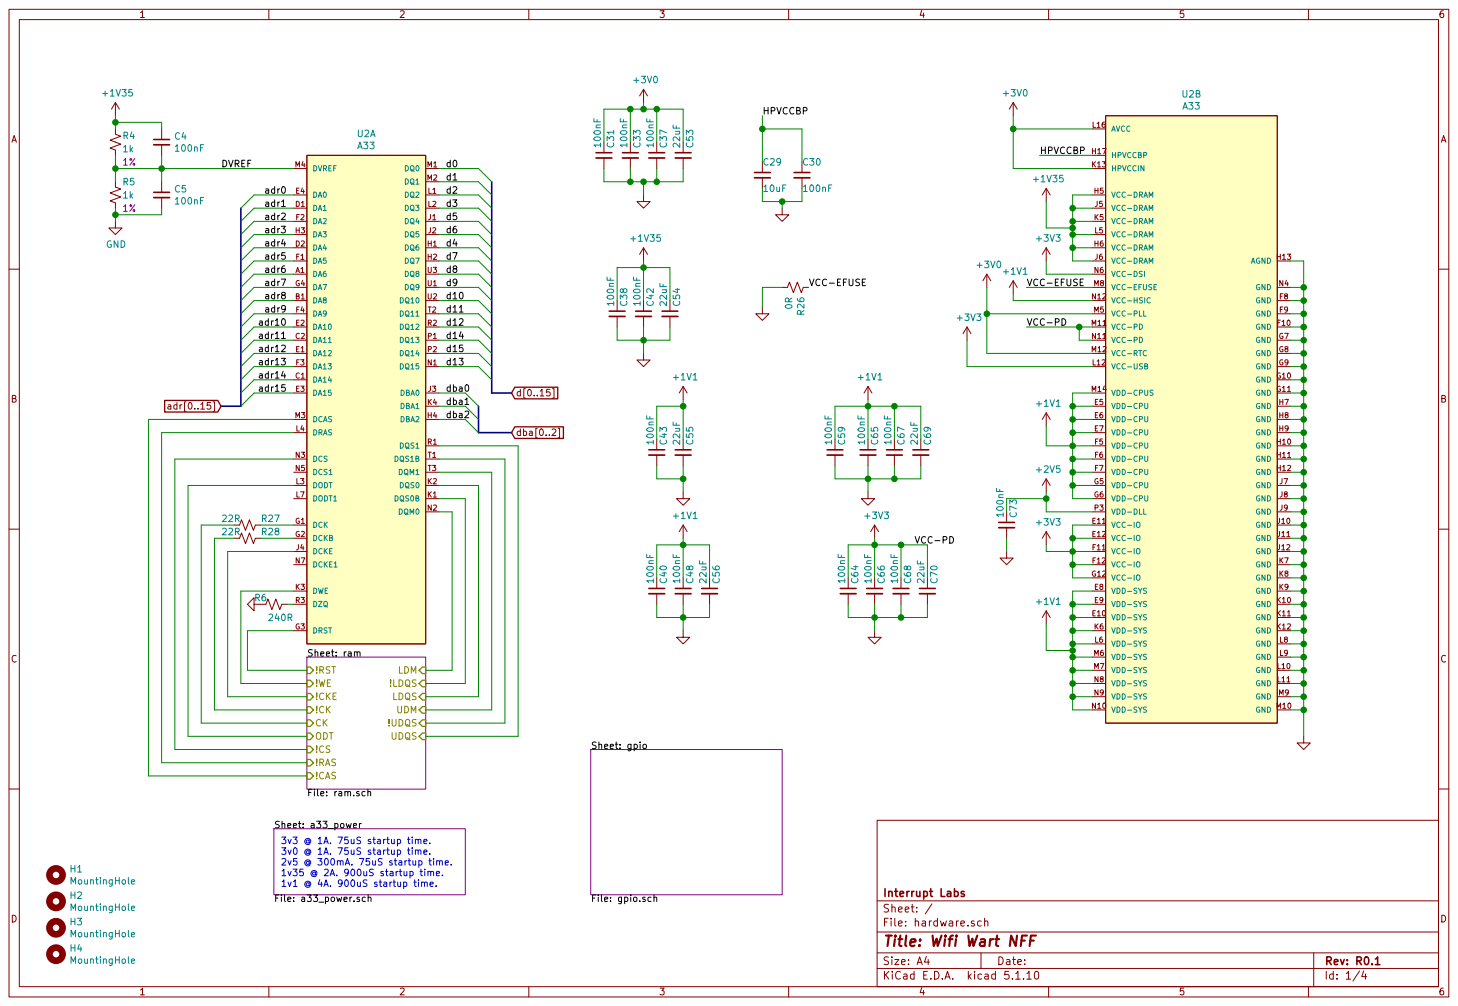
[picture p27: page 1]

Interrupt Labs
File: hardware.sch Sheet: /
Id: 1/4 Title: Wifi Wart NFF

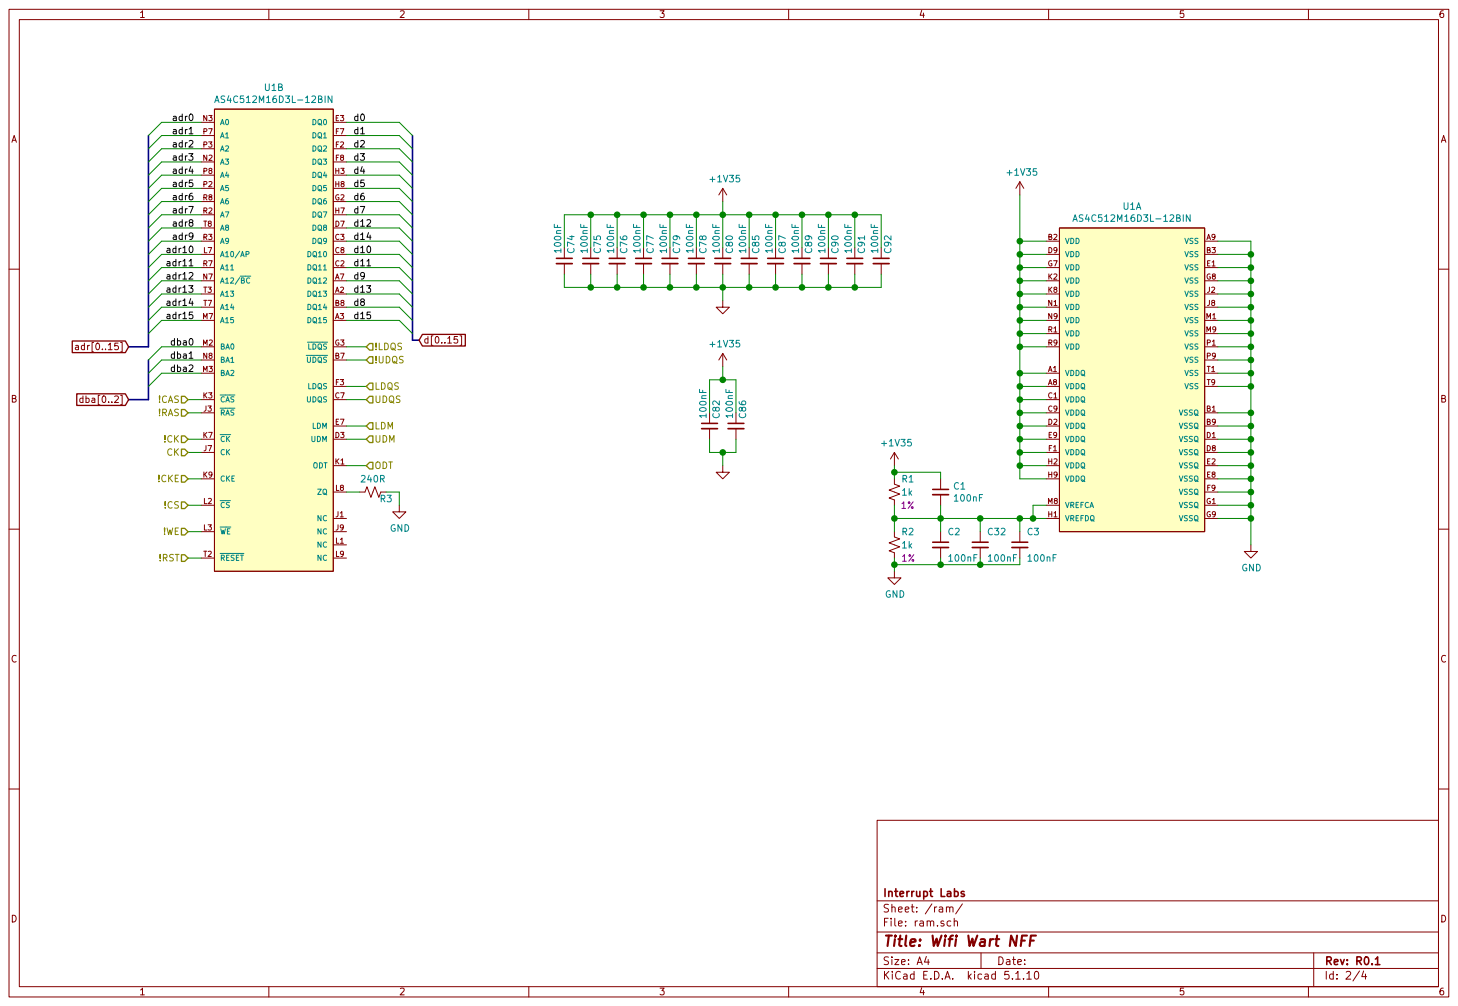
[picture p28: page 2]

File: ram.sch Sheet: /ram/
Id: 2/4 Title: Wifi Wart NFF

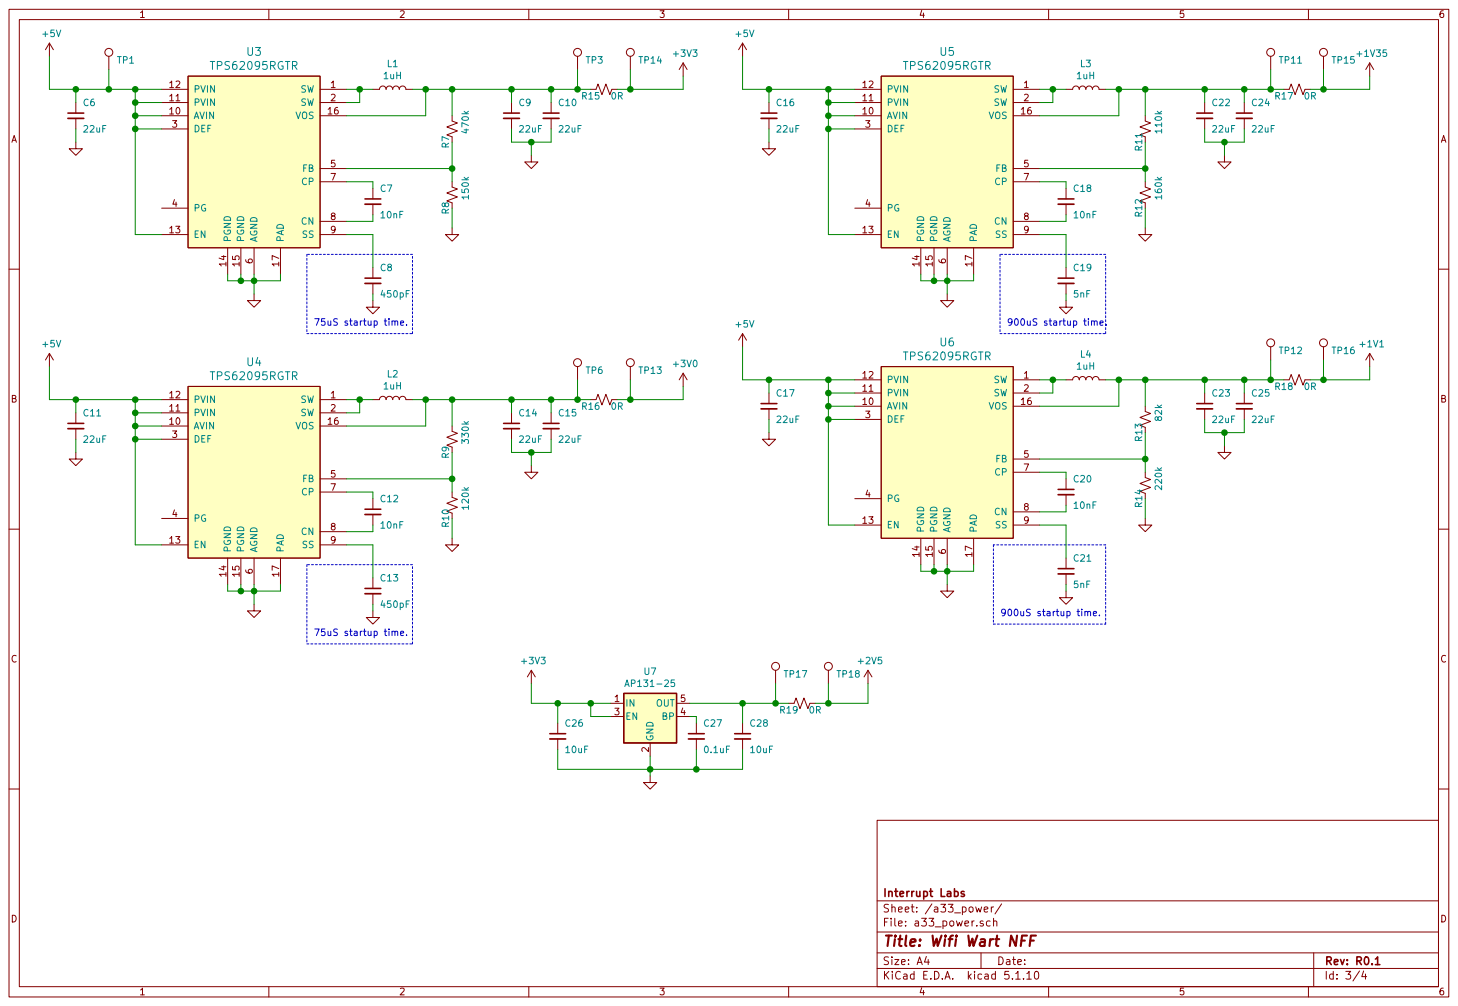
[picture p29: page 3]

Interrupt Labs
Sheet: /a33_power/
File: a33_power.sch
Id: 3/4 Title: Wifi Wart NFF

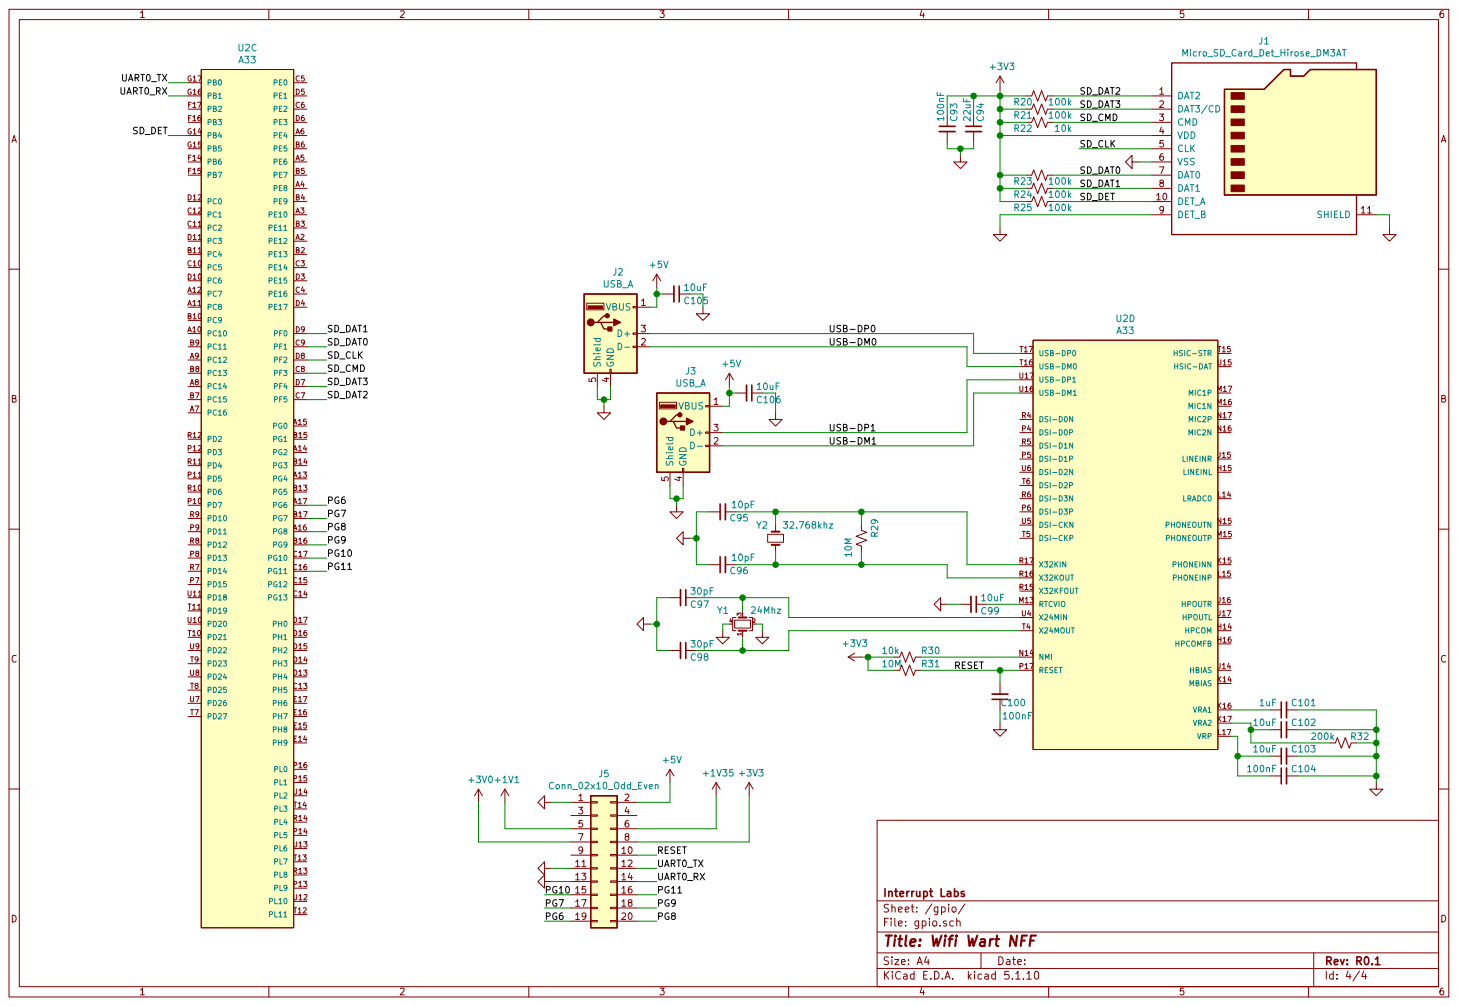
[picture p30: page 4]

Interrupt Labs
Sheet: /gpio/
File: gpio.sch
Id: 4/4 Title: Wifi Wart NFF

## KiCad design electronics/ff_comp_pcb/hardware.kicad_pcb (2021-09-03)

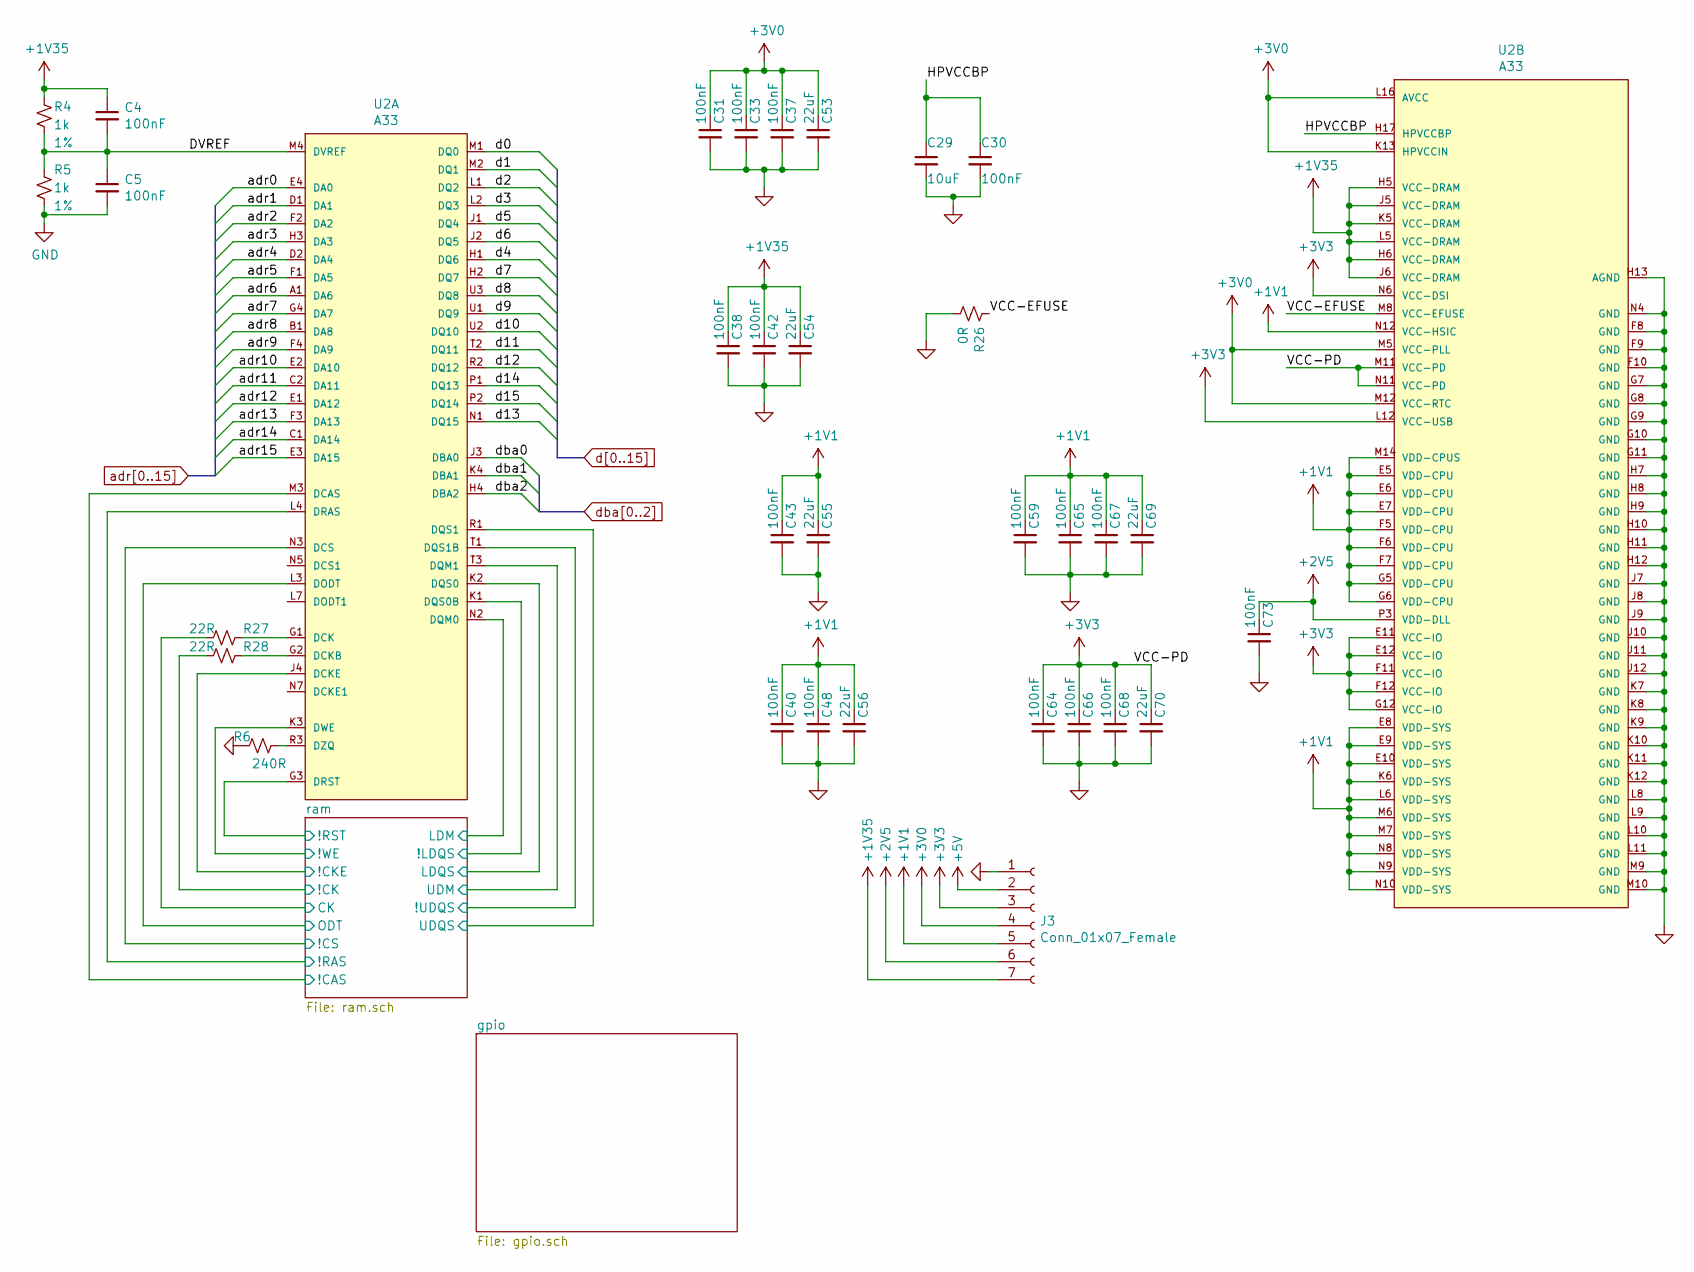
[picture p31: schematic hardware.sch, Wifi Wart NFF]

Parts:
C4, C5, C30, C31, C33, C37, C38, C40, C42, C43, C48, C59, C64, C65, C66, C67, C68, C73: 100nF; C_0402_1005Metric; MPN CC0402KRX7R7BB104
C29: 10uF; C_0402_1005Metric; MPN CL05A106MQ5NUNC
C53, C54, C55, C56, C69, C70: 22uF; C_0402_1005Metric; MPN GRM155R60J226ME11D
J3: Conn_01x07_Female; PinHeader_1x07_P2.54mm_Vertical
R4, R5: 1k; R_0402_1005Metric; Tolerance 1%; MPN 4-1879208-9
R6: 240R; R_0402_1005Metric; MPN 0402WGF2400TCE
R26: 0R; R_0402_1005Metric; MPN RC0402JR-070RL
R27, R28: 22R; R_0402_1005Metric; MPN RC0402JR-0722RL
U2: A33; Allwinner_Technology_Co.,_Ltd.-A33-0; MPN A33

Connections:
+1V1: C40.1, C43.1, C48.1, C55.1, C56.1, C59.1, C65.1, C67.1, C69.1, J3.5, U2.E5 (VDD-CPU), U2.E6 (VDD-CPU), U2.E7 (VDD-CPU), U2.E8 (VDD-SYS), U2.E9 (VDD-SYS), U2.E10 (VDD-SYS), U2.F5 (VDD-CPU), U2.F6 (VDD-CPU), U2.F7 (VDD-CPU), U2.G5 (VDD-CPU), U2.G6 (VDD-CPU), U2.K6 (VDD-SYS), U2.L6 (VDD-SYS), U2.M6 (VDD-SYS), U2.M7 (VDD-SYS), U2.M14 (VDD-CPUS), U2.N8 (VDD-SYS), U2.N9 (VDD-SYS), U2.N10 (VDD-SYS), U2.N12 (VCC-HSIC)
+1V35: C4.1, C38.1, C42.1, C54.1, J3.7, R4.1, U2.H5 (VCC-DRAM), U2.H6 (VCC-DRAM), U2.J5 (VCC-DRAM), U2.J6 (VCC-DRAM), U2.K5 (VCC-DRAM), U2.L5 (VCC-DRAM); also elsewhere on the board
+2V5: C73.1, J3.6, U2.P3 (VDD-DLL)
+3V0: C31.1, C33.1, C37.1, C53.1, J3.4, U2.K13 (HPVCCIN), U2.L16 (AVCC), U2.M5 (VCC-PLL), U2.M12 (VCC-RTC)
+3V3: C64.1, C66.1, C68.1, C70.1, J3.3, U2.E11 (VCC-IO), U2.E12 (VCC-IO), U2.F11 (VCC-IO), U2.F12 (VCC-IO), U2.G12 (VCC-IO), U2.L12 (VCC-USB), U2.M11 (VCC-PD), U2.N6 (VCC-DSI), U2.N11 (VCC-PD); also elsewhere on the board
+5V: J3.2; also elsewhere on the board
/DVREF: C4.2, C5.1, R4.2, R5.1, U2.M4 (DVREF)
/HPVCCBP: C29.1, C30.1, U2.H17 (HPVCCBP)
/VCC-EFUSE: R26.1, U2.M8 (VCC-EFUSE)
/ram/!CAS: U2.M3 (DCAS); also elsewhere on the board
/ram/!CK: R28.2; also elsewhere on the board
/ram/!CKE: U2.J4 (DCKE); also elsewhere on the board
/ram/!CS: U2.N3 (DCS); also elsewhere on the board
/ram/!LDQS: U2.K1 (DQS0B); also elsewhere on the board
/ram/!RAS: U2.L4 (DRAS); also elsewhere on the board
/ram/!RST: U2.G3 (DRST); also elsewhere on the board
/ram/!UDQS: U2.T1 (DQS1B); also elsewhere on the board
/ram/!WE: U2.K3 (DWE); also elsewhere on the board
/ram/CK: R27.2; also elsewhere on the board
/ram/LDM: U2.N2 (DQM0); also elsewhere on the board
/ram/LDQS: U2.K2 (DQS0); also elsewhere on the board
/ram/ODT: U2.L3 (DODT); also elsewhere on the board
/ram/UDM: U2.T3 (DQM1); also elsewhere on the board
/ram/UDQS: U2.R1 (DQS1); also elsewhere on the board
GND: C5.2, C29.2, C30.2, C31.2, C33.2, C37.2, C38.2, C40.2, C42.2, C43.2, C48.2, C53.2, C54.2, C55.2, C56.2, C59.2, C64.2, C65.2, C66.2, C67.2, C68.2, C69.2, C70.2, C73.2, J3.1, R5.2, R6.2, R26.2, U2.F8 (GND), U2.F9 (GND), U2.F10 (GND), U2.G7 (GND), U2.G8 (GND), U2.G9 (GND), U2.G10 (GND), U2.G11 (GND), U2.H7 (GND), U2.H8 (GND), U2.H9 (GND), U2.H10 (GND), U2.H11 (GND), U2.H12 (GND), U2.H13 (AGND), U2.J7 (GND), U2.J8 (GND), U2.J9 (GND), U2.J10 (GND), U2.J11 (GND), U2.J12 (GND), U2.K7 (GND), U2.K8 (GND), U2.K9 (GND), U2.K10 (GND), U2.K11 (GND), U2.K12 (GND), U2.L8 (GND), U2.L9 (GND), U2.L10 (GND), U2.L11 (GND), U2.M9 (GND), U2.M10 (GND), U2.N4 (GND); also elsewhere on the board
unnamed: R6.1, U2.R3 (DZQ)
unnamed: R27.1, U2.G1 (DCK)
unnamed: R28.1, U2.G2 (DCKB)
adr0: U2.E4 (DA0); also elsewhere on the board
adr1: U2.D1 (DA1); also elsewhere on the board
adr2: U2.F2 (DA2); also elsewhere on the board
adr3: U2.H3 (DA3); also elsewhere on the board
adr4: U2.D2 (DA4); also elsewhere on the board
adr5: U2.F1 (DA5); also elsewhere on the board
adr6: U2.A1 (DA6); also elsewhere on the board
adr7: U2.G4 (DA7); also elsewhere on the board
adr8: U2.B1 (DA8); also elsewhere on the board
adr9: U2.F4 (DA9); also elsewhere on the board
adr10: U2.E2 (DA10); also elsewhere on the board
adr11: U2.C2 (DA11); also elsewhere on the board
adr12: U2.E1 (DA12); also elsewhere on the board
adr13: U2.F3 (DA13); also elsewhere on the board
adr14: U2.C1 (DA14); also elsewhere on the board
adr15: U2.E3 (DA15); also elsewhere on the board
d0: U2.M1 (DQ0); also elsewhere on the board
d1: U2.M2 (DQ1); also elsewhere on the board
d2: U2.L1 (DQ2); also elsewhere on the board
d3: U2.L2 (DQ3); also elsewhere on the board
d4: U2.H1 (DQ6); also elsewhere on the board
d5: U2.J1 (DQ4); also elsewhere on the board
d6: U2.J2 (DQ5); also elsewhere on the board
d7: U2.H2 (DQ7); also elsewhere on the board
d8: U2.U3 (DQ8); also elsewhere on the board
d9: U2.U1 (DQ9); also elsewhere on the board
d10: U2.U2 (DQ10); also elsewhere on the board
d11: U2.T2 (DQ11); also elsewhere on the board
d12: U2.R2 (DQ12); also elsewhere on the board
d13: U2.N1 (DQ15); also elsewhere on the board
d14: U2.P1 (DQ13); also elsewhere on the board
d15: U2.P2 (DQ14); also elsewhere on the board
dba0: U2.J3 (DBA0); also elsewhere on the board
dba1: U2.K4 (DBA1); also elsewhere on the board
dba2: U2.H4 (DBA2); also elsewhere on the board

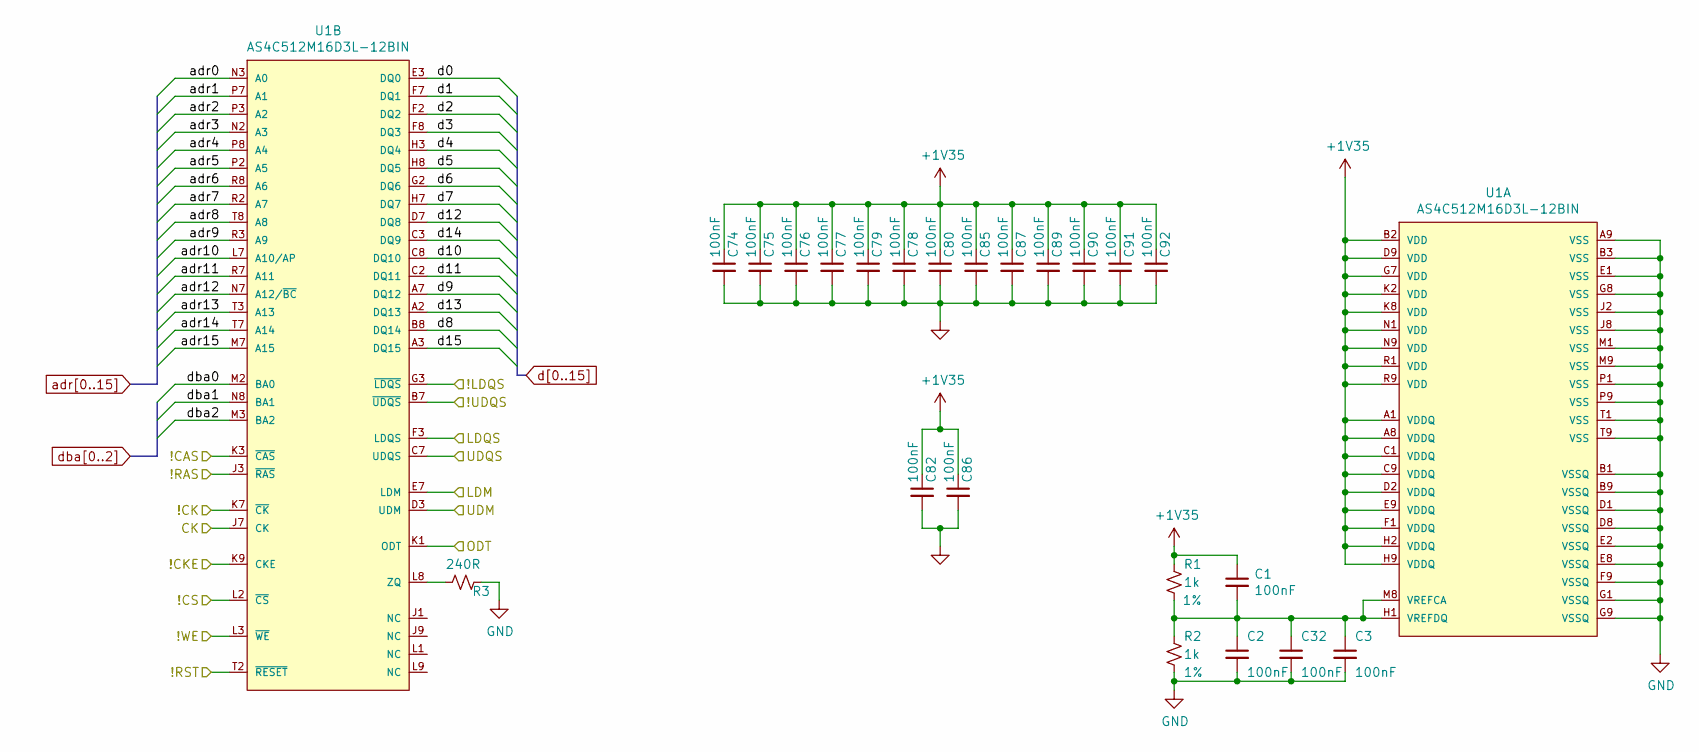
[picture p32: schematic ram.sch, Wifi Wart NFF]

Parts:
C1, C2, C3, C32, C74, C75, C76, C77, C78, C79, C80, C82, C85, C86, C87, C89, C90, C91, C92: 100nF; C_0402_1005Metric; MPN CC0402KRX7R7BB104
R1, R2: 1k; R_0402_1005Metric; Tolerance 1%; MPN 4-1879208-9
R3: 240R; R_0402_1005Metric; MPN 0402WGF2400TCE
U1: AS4C512M16D3L-12BIN; Alliance_Memory-AS4C512M16D3L-12BIN-0-0-IPC_A; MPN AS4C512M16D3L-12BIN

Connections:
+1V35: C1.1, C74.1, C75.1, C76.1, C77.1, C78.1, C79.1, C80.1, C82.1, C85.1, C86.1, C87.1, C89.1, C90.1, C91.1, C92.1, R1.1, U1.A1 (VDDQ), U1.A8 (VDDQ), U1.B2 (VDD), U1.C1 (VDDQ), U1.C9 (VDDQ), U1.D2 (VDDQ), U1.D9 (VDD), U1.E9 (VDDQ), U1.F1 (VDDQ), U1.G7 (VDD), U1.H2 (VDDQ), U1.H9 (VDDQ), U1.K2 (VDD), U1.K8 (VDD), U1.N1 (VDD), U1.N9 (VDD), U1.R1 (VDD), U1.R9 (VDD); also elsewhere on the board
/ram/!CAS: U1.K3 (~CAS~); also elsewhere on the board
/ram/!CK: U1.K7 (~CK~); also elsewhere on the board
/ram/!CKE: U1.K9 (CKE); also elsewhere on the board
/ram/!CS: U1.L2 (~CS~); also elsewhere on the board
/ram/!LDQS: U1.G3 (~LDQS~); also elsewhere on the board
/ram/!RAS: U1.J3 (~RAS~); also elsewhere on the board
/ram/!RST: U1.T2 (~RESET~); also elsewhere on the board
/ram/!UDQS: U1.B7 (~UDQS~); also elsewhere on the board
/ram/!WE: U1.L3 (~WE~); also elsewhere on the board
/ram/CK: U1.J7 (CK); also elsewhere on the board
/ram/LDM: U1.E7 (LDM); also elsewhere on the board
/ram/LDQS: U1.F3 (LDQS); also elsewhere on the board
/ram/ODT: U1.K1 (ODT); also elsewhere on the board
/ram/UDM: U1.D3 (UDM); also elsewhere on the board
/ram/UDQS: U1.C7 (UDQS); also elsewhere on the board
GND: C2.2, C3.2, C32.2, C74.2, C75.2, C76.2, C77.2, C78.2, C79.2, C80.2, C82.2, C85.2, C86.2, C87.2, C89.2, C90.2, C91.2, C92.2, R2.2, R3.1, U1.A9 (VSS), U1.B1 (VSSQ), U1.B3 (VSS), U1.B9 (VSSQ), U1.D1 (VSSQ), U1.D8 (VSSQ), U1.E1 (VSS), U1.E2 (VSSQ), U1.E8 (VSSQ), U1.F9 (VSSQ), U1.G1 (VSSQ), U1.G8 (VSS), U1.G9 (VSSQ), U1.J2 (VSS), U1.J8 (VSS), U1.M1 (VSS), U1.M9 (VSS), U1.P1 (VSS), U1.P9 (VSS), U1.T1 (VSS), U1.T9 (VSS); also elsewhere on the board
unnamed: C1.2, C2.1, C3.1, C32.1, R1.2, R2.1, U1.H1 (VREFDQ), U1.M8 (VREFCA)
unnamed: R3.2, U1.L8 (ZQ)
adr0: U1.N3 (A0); also elsewhere on the board
adr1: U1.P7 (A1); also elsewhere on the board
adr2: U1.P3 (A2); also elsewhere on the board
adr3: U1.N2 (A3); also elsewhere on the board
adr4: U1.P8 (A4); also elsewhere on the board
adr5: U1.P2 (A5); also elsewhere on the board
adr6: U1.R8 (A6); also elsewhere on the board
adr7: U1.R2 (A7); also elsewhere on the board
adr8: U1.T8 (A8); also elsewhere on the board
adr9: U1.R3 (A9); also elsewhere on the board
adr10: U1.L7 (A10/AP); also elsewhere on the board
adr11: U1.R7 (A11); also elsewhere on the board
adr12: U1.N7 (A12/~BC~); also elsewhere on the board
adr13: U1.T3 (A13); also elsewhere on the board
adr14: U1.T7 (A14); also elsewhere on the board
adr15: U1.M7 (A15); also elsewhere on the board
d0: U1.E3 (DQ0); also elsewhere on the board
d1: U1.F7 (DQ1); also elsewhere on the board
d2: U1.F2 (DQ2); also elsewhere on the board
d3: U1.F8 (DQ3); also elsewhere on the board
d4: U1.H3 (DQ4); also elsewhere on the board
d5: U1.H8 (DQ5); also elsewhere on the board
d6: U1.G2 (DQ6); also elsewhere on the board
d7: U1.H7 (DQ7); also elsewhere on the board
d8: U1.B8 (DQ14); also elsewhere on the board
d9: U1.A7 (DQ12); also elsewhere on the board
d10: U1.C8 (DQ10); also elsewhere on the board
d11: U1.C2 (DQ11); also elsewhere on the board
d12: U1.D7 (DQ8); also elsewhere on the board
d13: U1.A2 (DQ13); also elsewhere on the board
d14: U1.C3 (DQ9); also elsewhere on the board
d15: U1.A3 (DQ15); also elsewhere on the board
dba0: U1.M2 (BA0); also elsewhere on the board
dba1: U1.N8 (BA1); also elsewhere on the board
dba2: U1.M3 (BA2); also elsewhere on the board

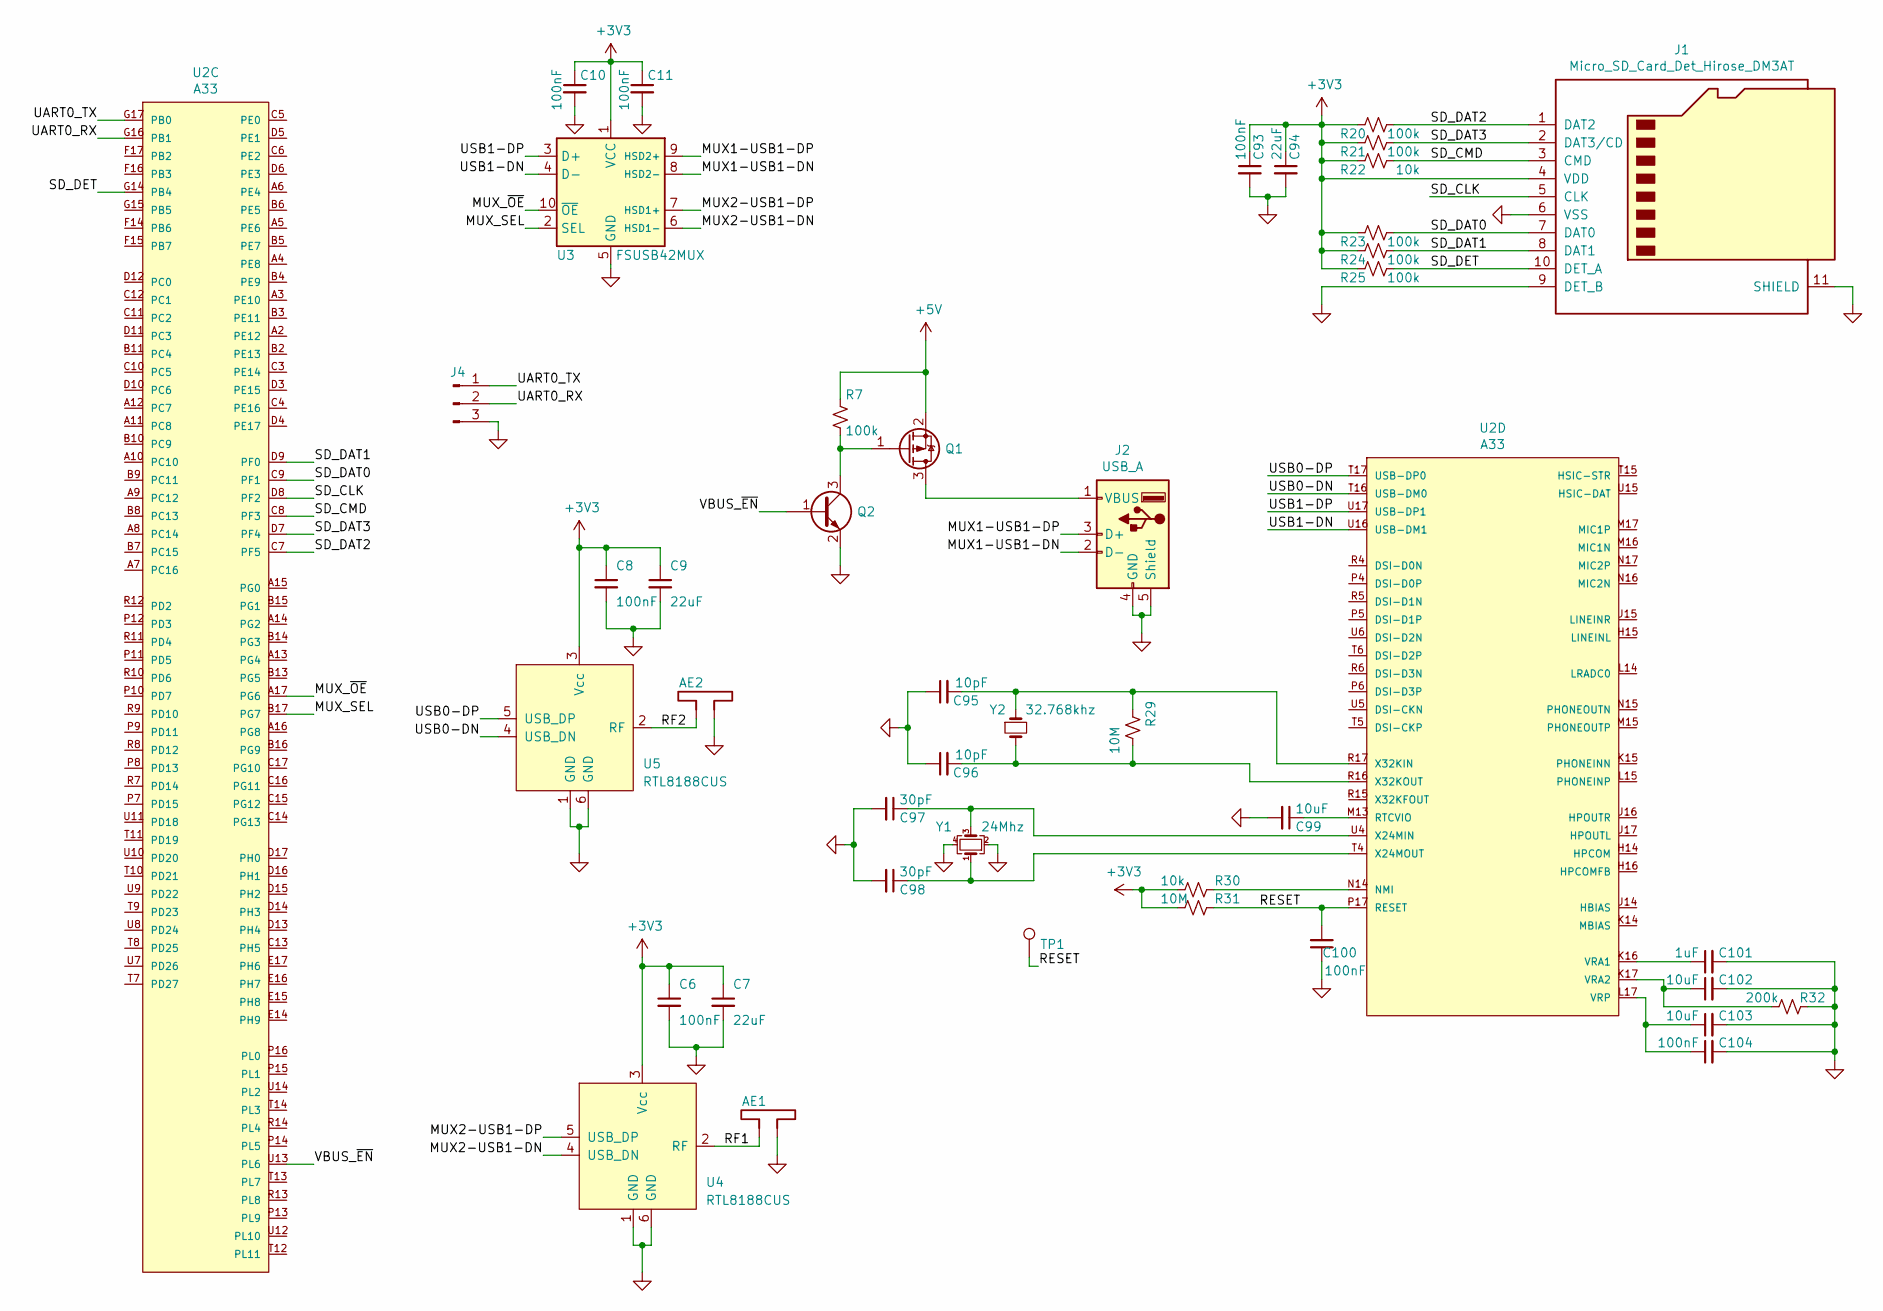
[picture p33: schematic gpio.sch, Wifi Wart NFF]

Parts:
AE1, AE2: Antenna_Dipole; U.FL_Hirose_U.FL-R-SMT-1_Vertical; MPN U.FL-R-SMT-1(10)
C6, C8, C10, C11, C93, C100, C104: 100nF; C_0402_1005Metric; MPN CC0402KRX7R7BB104
C7, C9, C94: 22uF; C_0402_1005Metric; MPN GRM155R60J226ME11D
C95, C96: 10pF; C_0402_1005Metric; MPN CC0402JRNPO9BN100
C97, C98: 30pF; C_0402_1005Metric; MPN CC0402JRNPO9BN300
C99, C102, C103: 10uF; C_0402_1005Metric; MPN CL05A106MQ5NUNC
C101: 1uF; C_0402_1005Metric; MPN CL05A105KO5NNNC
J1: Micro_SD_Card_Det_Hirose_DM3AT; microSD_HC_Hirose_DM3AT-SF-PEJM5; MPN DM3AT-SF-PEJM5
J2: USB_A; USB_A_Molex_67643_Horizontal; MPN 676430910
J4: Conn_01x03_Male; PinHeader_1x03_P2.54mm_Vertical
Q1: Q_PMOS_GSD; SOT-23; MPN SSM3J328R,LF
Q2: Q_NPN_BEC; SOT-23; MPN MMBT2369ALT1G
R7, R20, R21, R23, R24, R25: 100k; R_0402_1005Metric; MPN CR0402-JW-104GLF
R22, R30: 10k; R_0402_1005Metric; MPN RC0402JR-0710KL
R29, R31: 10M; R_0402_1005Metric; MPN 0402WGJ0106TCE
R32: 200k; R_0402_1005Metric; MPN RC0402FR-07200KL
TP1: TestPoint; TestPoint_Pad_2.0x2.0mm
U2: A33; Allwinner_Technology_Co.,_Ltd.-A33-0; MPN A33
U3: FSUSB42MUX; MSOP-10_3x3mm_P0.5mm; MPN FSUSB42MUX
U4, U5: RTL8188CUS; MPN RTL8188CUS
Y1: 24Mhz; Crystal_SMD_Abracon_ABM8G-4Pin_3.2x2.5mm; MPN ABM8G-24.000MHZ-18-D2Y-T
Y2: 32.768khz; Abracon-ABS05-0-0-MFG; MPN ABS05-32.768KHZ-9-T

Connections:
+3V3: C6.1, C7.1, C8.1, C9.1, C10.1, C11.1, C93.1, C94.1, J1.4 (VDD), R20.1, R21.1, R22.1, R23.1, R24.1, R25.1, R30.2, R31.2, U3.1 (VCC), U4.3 (Vcc), U5.3 (Vcc); also elsewhere on the board
+5V: Q1.2 (S), R7.1; also elsewhere on the board
/gpio/MUX1-USB1-DN: J2.2 (D-), U3.8 (HSD2-)
/gpio/MUX1-USB1-DP: J2.3 (D+), U3.9 (HSD2+)
/gpio/MUX2-USB1-DN: U3.6 (HSD1-), U4.4 (USB_DN)
/gpio/MUX2-USB1-DP: U3.7 (HSD1+), U4.5 (USB_DP)
/gpio/MUX_SEL: U2.B17 (PG7), U3.2 (SEL)
/gpio/MUX_~OE: U2.A17 (PG6), U3.10 (~OE)
/gpio/RESET: C100.2, R31.1, TP1.1, U2.P17 (RESET)
/gpio/RF1: AE1.1, U4.2 (RF)
/gpio/RF2: AE2.1, U5.2 (RF)
/gpio/SD_CLK: J1.5 (CLK), U2.D8 (PF2)
/gpio/SD_CMD: J1.3 (CMD), R22.2, U2.C8 (PF3)
/gpio/SD_DAT0: J1.7 (DAT0), R23.2, U2.C9 (PF1)
/gpio/SD_DAT1: J1.8 (DAT1), R24.2, U2.D9 (PF0)
/gpio/SD_DAT2: J1.1 (DAT2), R20.2, U2.C7 (PF5)
/gpio/SD_DAT3: J1.2 (DAT3/CD), R21.2, U2.D7 (PF4)
/gpio/SD_DET: J1.10 (DET_A), R25.2, U2.G14 (PB4)
/gpio/UART0_RX: J4.2, U2.G16 (PB1)
/gpio/UART0_TX: J4.1, U2.G17 (PB0)
/gpio/USB0-DN: U2.T16 (USB-DM0), U5.4 (USB_DN)
/gpio/USB0-DP: U2.T17 (USB-DP0), U5.5 (USB_DP)
/gpio/USB1-DN: U2.U16 (USB-DM1), U3.4 (D-)
/gpio/USB1-DP: U2.U17 (USB-DP1), U3.3 (D+)
/gpio/VBUS_~EN: Q2.1 (B), U2.U13 (PL6)
GND: AE1.2, AE2.2, C6.2, C7.2, C8.2, C9.2, C10.2, C11.2, C93.2, C94.2, C95.1, C96.1, C97.2, C98.2, C99.2, C100.1, C101.2, C102.2, C103.2, C104.2, J1.6 (VSS), J1.9 (DET_B), J1.11 (SHIELD), J2.4 (GND), J2.5 (Shield), J4.3, Q2.2 (E), R32.1, U3.5 (GND), U4.1 (GND), U4.6 (GND), U5.1 (GND), U5.6 (GND), Y1.2, Y1.4; also elsewhere on the board
unnamed: C95.2, R29.1, U2.R17 (X32KIN), Y2.1
unnamed: C96.2, R29.2, U2.R16 (X32KOUT), Y2.2
unnamed: C97.1, U2.U4 (X24MIN), Y1.3
unnamed: C98.1, U2.T4 (X24MOUT), Y1.1
unnamed: C99.1, U2.M13 (RTCVIO)
unnamed: C101.1, U2.K16 (VRA1)
unnamed: C102.1, R32.2, U2.K17 (VRA2)
unnamed: C103.1, C104.1, U2.L17 (VRP)
unnamed: J2.1 (VBUS), Q1.3 (D)
unnamed: Q1.1 (G), Q2.3 (C), R7.2
unnamed: R30.1, U2.N14 (NMI)

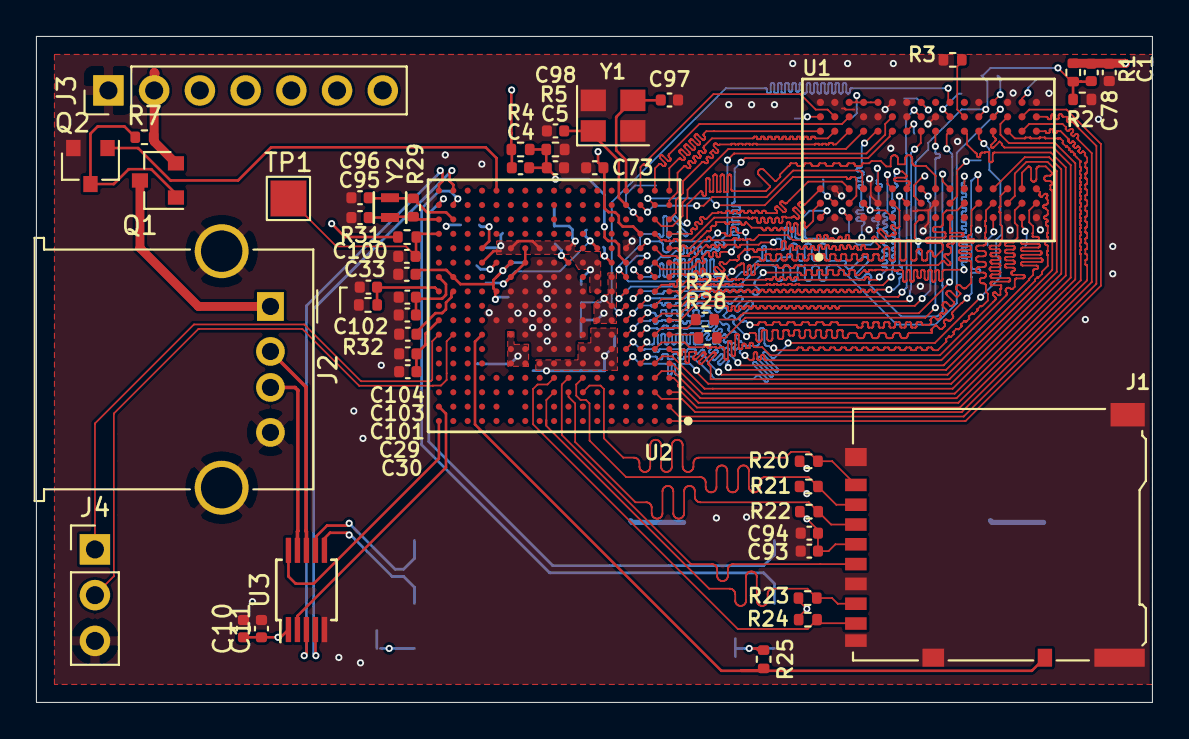
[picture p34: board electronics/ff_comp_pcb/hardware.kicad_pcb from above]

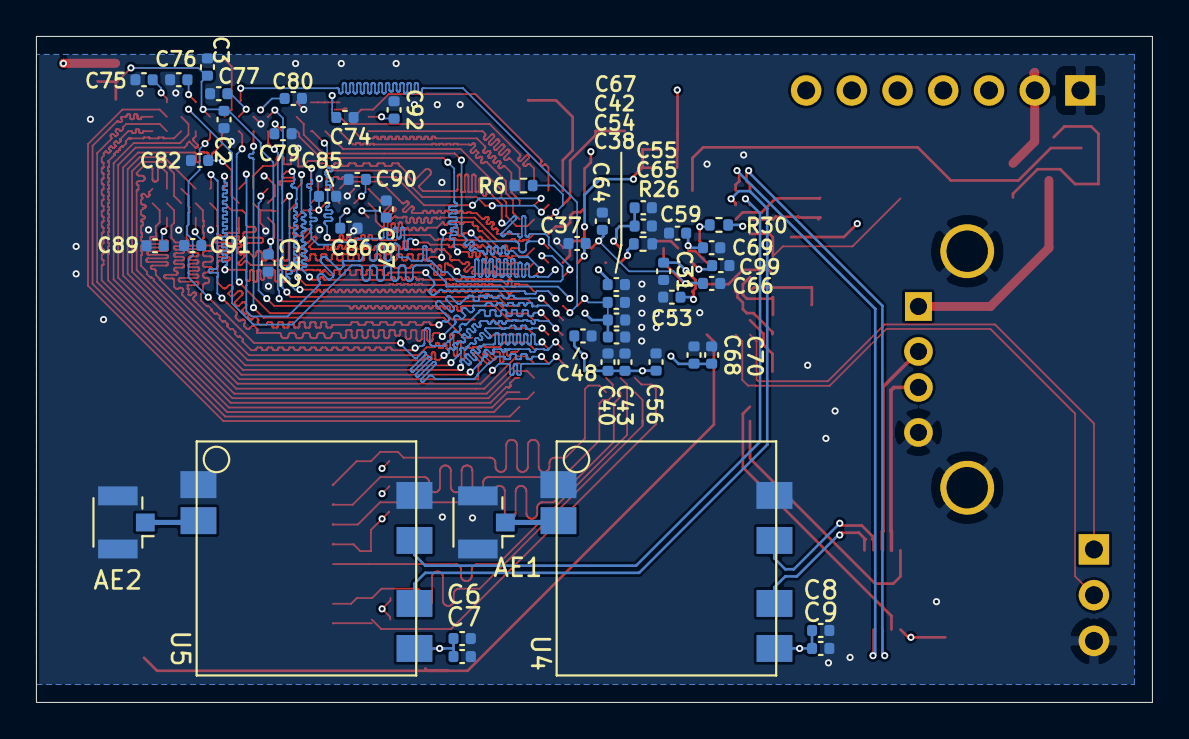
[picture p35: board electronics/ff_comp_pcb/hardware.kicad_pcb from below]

Board: 4 copper layers, 62.0 x 37.0 mm, 98 parts (48 on the bottom side), 99 nets.

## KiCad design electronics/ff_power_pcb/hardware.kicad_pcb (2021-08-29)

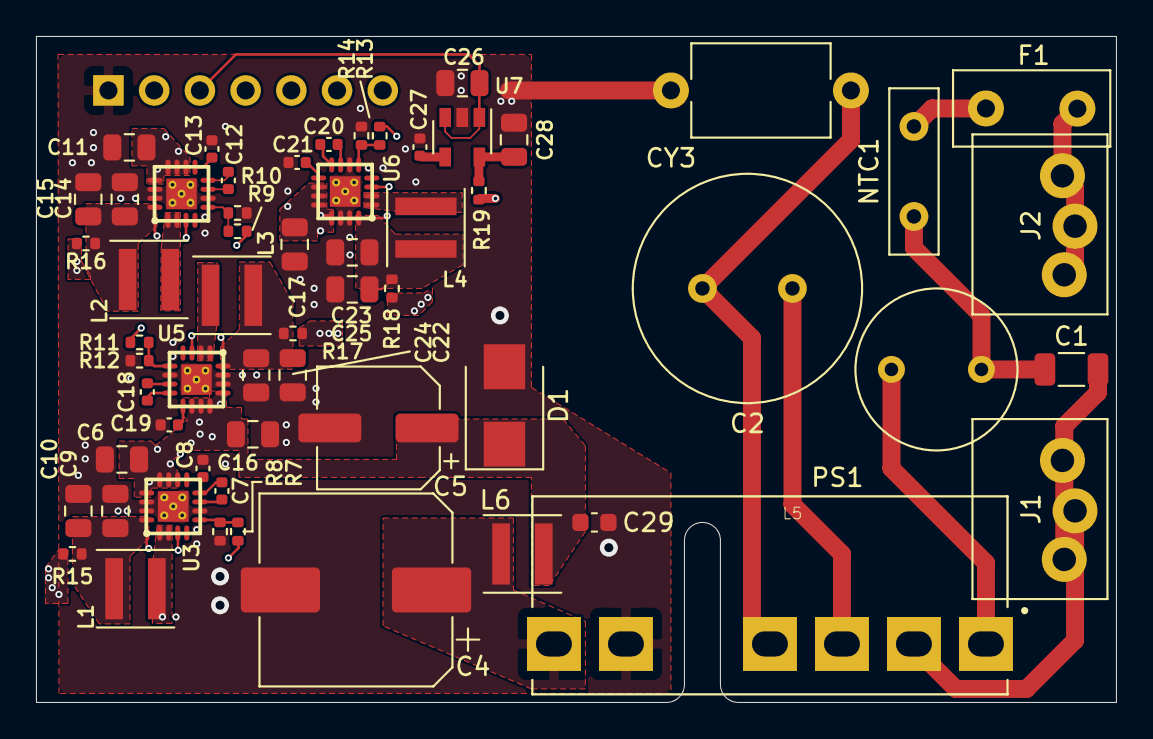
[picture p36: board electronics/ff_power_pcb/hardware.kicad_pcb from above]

Board: 4 copper layers, 60.0 x 37.0 mm, 60 parts (1 on the bottom side), 41 nets.

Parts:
C1: 0.1uF; C_1206_3216Metric
C2: 10uF; C_Radial_D12.5mm_H20.0mm_P5.00mm
C4: 470uF; CP_Elec_10x12.5
C5: 100uF; CP_Elec_6.3x5.8
C6, C9, C10, C11, C14, C15, C16, C17, C22, C23, C24, C25: 22uF; C_0805_2012Metric
C7, C12, C18, C20: 10nF; C_0402_1005Metric
C8, C13: 450pF; C_0402_1005Metric
C19, C21: 5nF; C_0402_1005Metric
C26, C28: 10uF; C_0805_2012Metric
C27: 0.1uF; C_0402_1005Metric
C29: 0.1uF; C_0603_1608Metric
CY3: 1.0nF; C_Disc_D7.5mm_W5.0mm_P10.00mm
D1: SMBJ7.0A; D_SMB
F1: 1A/300V Slow; Fuse_Littelfuse_395Series
J1, J2: Conn_01x01_Female; IRL_00
J3: Conn_01x07_Male; PinSocket_1x07_P2.54mm_Vertical
L1, L2, L3, L4: 1uH; L_Coilcraft_XxL4020
L5: 1.2mH; RLB9012
L6: 4.7uH; L_Coilcraft_XxL4030
NTC1: 10R; C_Disc_D9.0mm_W2.5mm_P5.00mm
PS1: PBO-5C-5; CONV_PBO-5C-12
R7: 470k; R_0402_1005Metric
R8: 150k; R_0402_1005Metric
R9: 330k; R_0402_1005Metric
R10: 120k; R_0402_1005Metric
R11: 110k; R_0402_1005Metric
R12: 160k; R_0402_1005Metric
R13: 82k; R_0402_1005Metric
R14: 220k; R_0402_1005Metric
R15, R16, R17, R18, R19: 0R; R_0402_1005Metric
U3, U4, U5, U6: TPS62095RGTR; TI_RTE_S-PWQFN-N16
U7: AP131-25; SOT-23-5

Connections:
+1V1: J3.5, R18.1
+1V35: J3.7, R17.1
+2V5: J3.6, R19.1
+3V0: J3.4, R16.1
+3V3: C26.1, J3.3, R15.1, U7.1, U7.3
+5V: C5.1, C6.1, C11.1, C16.1, C17.1, C29.1, D1.1, J3.2, L6.2, U3.3, U3.10, U3.11, U3.12, U3.13, U4.3, U4.10, U4.11, U4.12, U4.13, U5.3, U5.10, U5.11, U5.12, U5.13, U6.3, U6.10, U6.11, U6.12, U6.13
/AC_L: F1.2, J2.1
/AC_N: C1.2, J1.1, PS1.2
GND: C4.2, C5.2, C6.2, C8.2, C9.2, C10.2, C11.2, C13.2, C14.2, C15.2, C16.2, C17.2, C19.2, C21.2, C22.2, C23.2, C24.2, C25.2, C26.2, C27.2, C28.2, C29.2, CY3.1, D1.2, J3.1, PS1.5, R8.2, R10.2, R12.2, R14.2, U3.6, U3.14, U3.15, U3.17, U4.6, U4.14, U4.15, U4.17, U5.6, U5.14, U5.15, U5.17, U6.6, U6.14, U6.15, U6.17, U7.2
unnamed: C1.1, L5.1, NTC1.1
unnamed: C2.1, PS1.3
unnamed: C2.2, CY3.2, PS1.4
unnamed: C4.1, L6.1, PS1.6
unnamed: C7.1, U3.7
unnamed: C7.2, U3.8
unnamed: C8.1, U3.9
unnamed: C9.1, C10.1, L1.2, R7.1, R15.2, U3.16
unnamed: C12.1, U4.7
unnamed: C12.2, U4.8
unnamed: C13.1, U4.9
unnamed: C14.1, C15.1, L2.2, R9.1, R16.2, U4.16
unnamed: C18.1, U5.7
unnamed: C18.2, U5.8
unnamed: C19.1, U5.9
unnamed: C20.1, U6.7
unnamed: C20.2, U6.8
unnamed: C21.1, U6.9
unnamed: C22.1, C24.1, L3.2, R11.1, R17.2, U5.16
unnamed: C23.1, C25.1, L4.2, R13.1, R18.2, U6.16
unnamed: C27.1, U7.4
unnamed: C28.1, R19.2, U7.5
unnamed: F1.1, NTC1.2
unnamed: L1.1, U3.1, U3.2
unnamed: L2.1, U4.1, U4.2
unnamed: L3.1, U5.1, U5.2
unnamed: L4.1, U6.1, U6.2
unnamed: L5.2, PS1.1
unnamed: R7.2, R8.1, U3.5
unnamed: R9.2, R10.1, U4.5
unnamed: R11.2, R12.1, U5.5
unnamed: R13.2, R14.1, U6.5

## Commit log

2021-03-18 Finished up all the switching power supplies.
    [a33_power.sch]
2021-03-18 Added the inductor PN in and dropped them on the board.
    [a33_power.sch]
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2021-03-18 Finished connecting up the RAM
    [gpio.sch, hardware.sch]
2021-03-18 Added the 2.5V LDO
    [a33_power.sch, hardware.kicad_pcb, hardware.sch]
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2021-03-23 Wired in the SD card
    [gpio.sch, hardware.sch]
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2021-03-25 Wired in the VCC-EFUSE stuff.
    [hardware.sch]
2021-03-25 Decoupled the ram and A33
    [hardware.sch, ram.sch]
2021-03-25 Decoupled the SD card.
    [gpio.sch]
2021-03-25 Just dropped all the parts on the board.
    [hardware.kicad_pcb]
2021-03-25 Added in the mains to 5V module, this will most likely be removed in the future.
    [MEAN_WELL_-_MPM-15-5.step, a33_power.sch, hardware.kicad_pcb]
2021-03-30 Figured out all the crystals
    [Abracon_-_ABS05-32.768KHZ-9-T.step, a33_power.sch, gpio.sch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]
2021-03-30 Wired in the NMI and reset pins.
    [gpio.sch, hardware.sch]
2021-03-30 Wired in some bias pins, not sure if these are needed or not?
    [gpio.sch]
2021-03-31 Wired in the USB connectors.
    [gpio.sch]
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2021-04-06 Working on the layout
    [hardware.kicad_pcb]
2021-04-07 Ram finally hooked up
    [hardware.kicad_pcb, ram.sch]
2021-04-13 All address buses length matched
    [hardware.kicad_pcb]
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2021-04-16 Length matching finally "complete"
    [hardware.kicad_pcb]
2021-04-16 Added in the model for the 2x USB's
    [1050570001.stp, hardware.kicad_pcb]
2021-04-19 Working on the power supplies
    [a33_power.sch, hardware.kicad_pcb, hardware.sch]
2021-04-22 Working on the routing.
    [hardware.kicad_pcb, hardware.sch]
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2021-04-27 Working on the board
    [hardware.kicad_pcb]
2021-04-29 Working on the routing
    [Coilcraft-XAL4020.step, QFN-3x3.step, gpio.sch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]
2021-04-29 Still working on the routing.
    [a33_power.sch, gpio.sch, hardware.kicad_pcb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]
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2021-05-04 Moving stuff around again
    [1050570001.stp, AW-A33.step, Abracon_-_ABS05-32.768KHZ-9-T.step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]
2021-05-04 Working on getting all the DRC out.
    [hardware.kicad_pcb]
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2021-05-06 Added tolerances
    [hardware.kicad_pcb, hardware.sch, ram.sch]
2021-05-06 Working through the checklist
    [hardware.kicad_pcb, hardware.sch]
2021-05-10 Reworked 3.3V
    [hardware.kicad_pcb]
2021-05-10 Pulled out reset line
    [gpio.sch, hardware.kicad_pcb, hardware.sch]
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2021-05-12 Working on the length matching
    [hardware.kicad_pcb]
2021-05-12 Length matching finished, again lol
    [hardware.kicad_pcb]
2021-05-12 Fixed DRC, moved silk around.
    [hardware.kicad_pcb]
2021-05-13 DRC + BOM script
    [a33_power.sch, gpio.sch, hardware.kicad_pcb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]
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2021-05-13 Removed all the extra fields
    [a33_power.sch, gpio.sch, hardware.sch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]
2021-05-13 Added in all the part numbers
    [a33_power.sch, gpio.sch, hardware.csv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]
2021-05-13 Part numbers are _properly_ in now.
    [a33_power.sch, gpio.sch, hardware.sch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]
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2021-05-17 Forgot to save files.
    [hardware.kicad_pcb]
2021-05-20 Added some initial cad.
    [case.FCStd, lid.FCStd]
2021-05-21 Added some prong holes
    [case.FCStd, lid.FCStd, prong.FCStd]
2021-05-26 Made some changes to the mech and added a Gantt and notes.
    [case.FCStd, lid.FCStd, prong.FCStd]
2021-05-26 Moved some files around.
    [1050570001.stp, AW-A33.step, Abracon_-_ABS05-32.768KHZ-9-T.step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]
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2021-05-26 First stab at the ff power board.
    [Coilcraft-XAL4020.step, DM3AT-SF-PEJM5.stp, QFN-3x3.step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]
2021-05-26 Roughed in the transformer and whatnot.
    [hardware.sch]
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2021-05-26 Just made some notes, added apower budget.
    [case.FCStd, hardware.sch, lid.FCStd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]
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2021-05-27 Added the model for the usb, added a USB mux
    [676430910.stp, case.FCStd, gpio.sch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]
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2021-05-31 Added the step file of the board to the model, added a u.fl connector in.
    [case.FCStd, comp_pcb.FCStd, gpio.sch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]
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2021-06-05 Dopped all the parts down for the power supply.
    [hardware.kicad_pcb, hardware.sch]
2021-06-05 Added an app note of ntc current limiting, and added some part numbers into the schematic.
    [hardware.sch]
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2021-06-07 Dropped in the power board with all the new components.
    [case.FCStd, hardware.kicad_pcb, hardware.sch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]
2021-06-07 Shortened the legs of an inductor.
    [case.FCStd, hardware.kicad_pcb, power_pcb.FCStd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]
2021-06-08 Fit all the regulators into the power board.
    [case.FCStd, hardware.kicad_pcb, power_pcb.FCStd]
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2021-07-13 Changed out the 15W supply for a 5W.
    [PBO-5C-12.step, hardware.kicad_pcb, hardware.sch]
2021-07-23 Working on the electronics for the FF revision.
    [case.FCStd, hardware.kicad_pcb, hardware.sch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]
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2021-08-04 Added step files, Working on the power board.
    [36911000000.FCStd, 36911000000.step, Coilcraft-XAL4030.step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]
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2021-08-06 Finished up the routing on the power board, still needs a double check.
    [case.FCStd, comp_pcb.FCStd, gpio.sch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]
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2021-08-07 Power distrobution IP on the CPU board. Transistors in for 5V control. Part numbers in.
    [gpio.sch, hardware.kicad_pcb, hardware.sch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]
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2021-08-29 Rerouted the power traces for R0.1 power pcb - they didn't match the compute PCB power pins.
    [hardware-B_Cu.gbr, hardware-B_Mask.gbr, hardware-B_Paste.gbr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]
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2021-09-01 Updated the bom generation scripts, updated the BOM's and added a step file.
    [hardware.csv]
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2021-09-03 Headers were not aligned in comp_pcb, alligned them, created R0.2 and imported into assembly.
    [case.FCStd, comp_pcb.FCStd, hardware.kicad_pcb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]
2021-10-17 Added hole for SD card and two holes for the prongs.
    [case.FCStd, lid.FCStd, prong.FCStd]
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
